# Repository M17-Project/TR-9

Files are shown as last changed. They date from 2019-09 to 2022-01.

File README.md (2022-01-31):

# TR-9

TR-9 is a handheld transceiver (HT) for the M17 standard. Its specification can be found [here](https://github.com/sp5wwp/M17_spec).
This repo contains KiCAD schematics and gerber files. 

The source code has been moved to [M17-project/TR-9_firmware](https://github.com/m17-project/TR-9_firmware).
The codeplug example has been moved to [TR-9_Codeplug](https://github.com/M17-Project/codeplug)

# Capabilities
The TR-9 Radio will be capable of the following:
* UHF band (420 MHz - 450 MHz)
* Digital Voice ([M17 Codec](https://docs.m17project.org))
* FM Voice
* APRS via 1200 bps Packet (AX.25)
* Short text messaging (SMS-like)
* Optional Wi-Fi and GPS modules

# Hardware  
The heart of TR-9 is STM32F777VI microcontroller. The handheld also contains:  
*  a **DEM 128128A1 TMH-PWN** 1.44" 128x128px TFT display  
*  an **ESP8266-12F** WiFi module  
*  an **ADF7021** chip for the RF  
*  an **LSM9DS1** 9DoF sensor  
*  a USB-micro connector for firmware update (so-called *DFU mode*)  
*  an SD-micro card slot for codeplug and storage  
*  a connector for a GNSS module  
*  a Kenwood connector for external MIC/SPK  

RF output level can be regulated by the software. The maximum power output is 3 watts. The radio can work with both analog and digital modulation.  

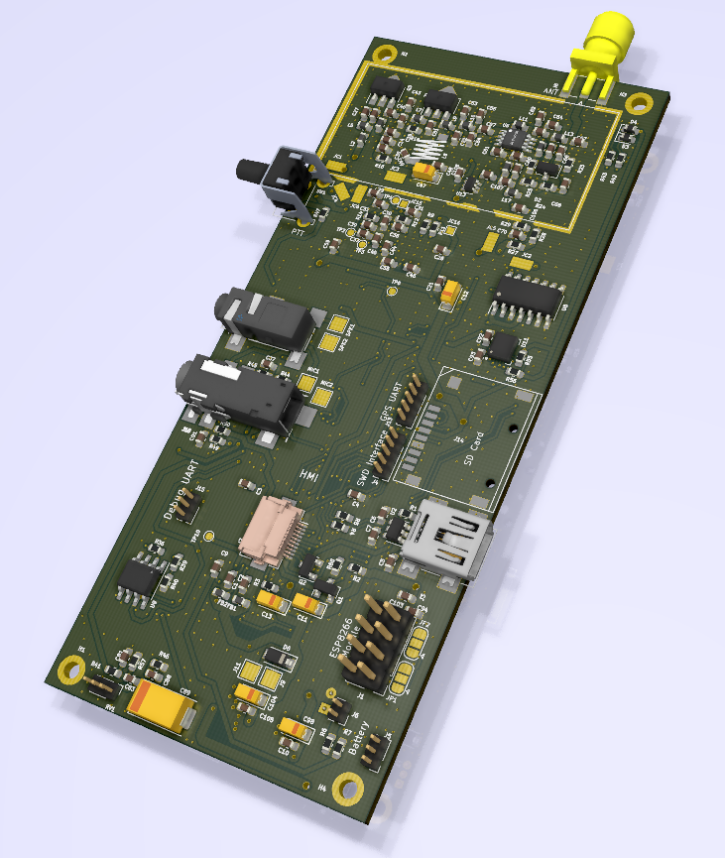
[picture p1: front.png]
TR-9


# Software
M17 standard was designed having [Codec2](https://github.com/drowe67/codec2) vocoder in mind. TR-9 takes advantage of STM's internal Advanced Encryption Standard (AES) hardware for optional end-to-end encryption. There is a possibility of using other block ciphers and scrambling.  

## Pinouts

Mainboard SWD/STLink: [GND, 3v3, CLK, DIO, RST], square pad is Pin 1 and therefore GND.

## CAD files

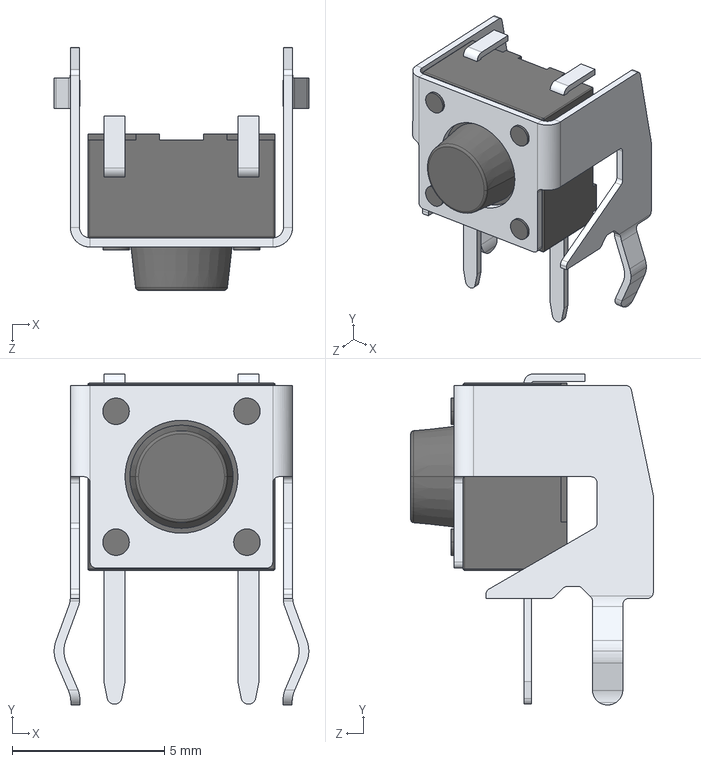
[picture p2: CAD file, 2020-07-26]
kicad/HMI/User Library-Alps TACT SKHH Horizontal Switch.step
8.37 x 10.9 x 7.97 mm

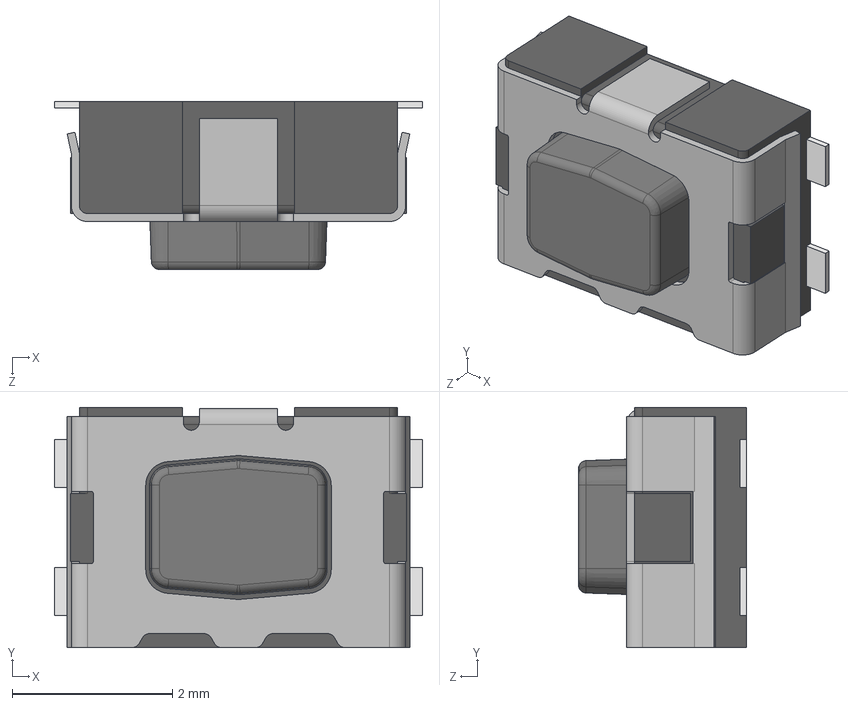
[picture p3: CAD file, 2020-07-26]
kicad/HMI/User Library-Switch-CK-KMR2.STEP
4.60 x 3.00 x 2.10 mm
Button
Boitier
Tole
Pads

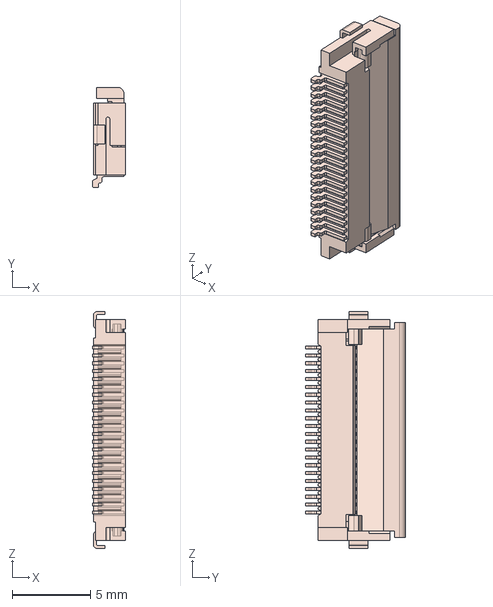
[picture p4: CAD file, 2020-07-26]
kicad/HMI/FH12-22S-0.5SH.step
2.10 x 6.40 x 15.1 mm

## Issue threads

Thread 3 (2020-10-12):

Power output

sp5wwp, 2020-10-12:
1. Power output is limited to 0.6W. Above that, the RF MOSFET gets HOT.
2. There's a high pitched sound audible when PA is active.

ALC circuitry works.

sp5wwp, 2020-10-12:
Squeak was eliminated by adding a 10k resistor in parallel to C106.

sp5wwp, 2020-11-12:
_Maybe_ we should get rid of Q3 (BGA6589).

tkuester, 2020-11-12:
Is this related to issue #8/9 in the errata, about R64 and C106?

sp5wwp, 2020-11-12:
@tkuester yes, it is.

sp5wwp, 2020-11-14:
The RF lowpass stage (around L9, L10) has to be redesigned.

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

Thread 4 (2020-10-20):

AX5043 as RFIC?

radonyl, 2020-10-20:
since APRS(AFSK mod) and analog FM are listed in feature list, I'd recommend AX5043 as the RFIC which has **AFSK demod embedded** (vital for power saving by WOR mode) and also analog mode(even AM). check [this project](https://www.notblackmagic.com/projects/vuhf-radio/) for a proof of practise.

Btw, AX5043's sensitivity is higher -126 vs -122 with even lower price 1.2$ vs 2.4$ and half current 10ma vs 20ma.

sp5wwp, 2020-11-12:
What is the roll-off factor for the Raised Cosine filter (AMPLSHAPE=1)?
I can't find any info here:
https://www.onsemi.com/pub/Collateral/AND9347-D.PDF

sp5wwp, 2022-01-31:
AX5043 is a cool little chip. I'm testing its performance right now. M17 mode TX is possible.

sp5wwp, 2022-01-31:
See [this gist](https://gist.github.com/sp5wwp/c612fc8fe612e99c11f9b65cd50bca3c).

ng91, 2022-01-31:
It's nice chip because it has many modulations that other chips lack of.

f4grx, 2022-02-01:
Definitely!

@sp5wwp thats great! BTW I suggest avoiding floating point in embedded code :)

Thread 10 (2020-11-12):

LED control lines

sp5wwp, 2020-11-12:
We need to add LED control lines (uhm... cathodes) to the interconnecting ribbon.

tkuester, 2020-11-12:
Would we like a power/status LEDs as well? What would we like them to represent? Which board do they belong on, the HMI or the Mainboard?

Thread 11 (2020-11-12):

Battery connector

sp5wwp, 2020-11-12:
Pads are too small, it's hard to solder wires to them.

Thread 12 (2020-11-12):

Unify edge mount tactile switch parts

tkuester, 2020-11-12:
Currently, both boards use the SKHH right angle through hole tactile switch, but they use different button depths. For ease of enclosure design and to reduce unique parts on the PCB, this should be consolidated.

What depth should we use for the next revision?

This issue from `ERRATA.txt`

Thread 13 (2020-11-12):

Split this repo

sp5wwp, 2020-11-12:
Split this repo into 3:
- firmware
- case design
- schematics/gerbers/BOM

tkuester, 2020-11-12:
I think this is a good decision -- especially for the firmware, which will change much faster than the hardware. At least for maintaining tags, there may be several revisions of firmware.

There may be some small utility in tracking the case design and PCB files all within one repository, such as keeping all the hardware issues in one place. If we wish to do things more incrementally (than all at once), perhaps it would be best to start with just two repositories: the firmware and hardware? This may be a little easier for other members in the project to track.

Closed 2020-11-14.

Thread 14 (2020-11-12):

HMI: Select the correct strap options for boot mode on the STM32

tkuester, 2020-11-12:
Per `ERRATA.txt`, pins 31 and 32 on U1 (STM32L011) should be shorted together to select the correct boot state. Tentatively, I've labeled this "bug", although I'm not sure what the implications of it are yet.

I suspect the best way to do this is with a pull down resistor. That is a little less "permanent" of a change, and permits easier bodge-wiring at a later date. Perhaps we can reuse a 47k 0603 -- or alternatively, kicad's "Jumper" if we want to save on soldering another part.

I took a brief look at the [datasheet, section 3.4.4](https://www.st.com/resource/en/datasheet/stm32l011d4.pdf). It indicates that there are several pins which control boot mode, can anyone confirm this needs to take place?

sp5wwp, 2020-11-12:
We probably wont have to leave that pin floating, so a pulldown or even a hard-tie to GND is OK.

tkuester, 2020-11-14:
Doing a bit more reading on the STM32 boot modes. I now understand that `PB9` is `BOOT0`, and `nBOOT{0,1}` and `nBOOT_SEL` are configuration bits.

I had to push some traces around a little to get the resistor to fit, but I don't think this is worth pushing yet -- I still don't understand enough about the STM32 to consider this ready. Is there any reason we would want `BOOT0` to be logic high? Or would this be a recovery scenario, and a bodge wire is tolerable?

I'm going to make a separate issue with a documentation request for compiling and flashing the firmware -- I think this would help better understand what the board needs!

sp5wwp, 2020-11-14:
There's no reason to put logic high on that pin.

Since it can be fixed with a solder blob, I'd leave this as is, mention this in ERRATA.txt and move on.

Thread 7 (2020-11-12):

Unify SWD header on TR-9 with HMI

tkuester, 2020-11-12:
As of 9ac1f05, the HMI board and the TR-9 share a different header layout for the SWD interface. Per a conversation with @sp5wwp, it would be nice to unify the headers to a common standard.

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

Some considerations I think are important:

 * Having the same ordering, and number of pins. If pin 1 (square pad) is GND on one board, it should be the same on the other
 * Having a common interface with common STM32 programmers. (Regrettably, I am new to the STM32 ecosystem, I'm not sure what's common.) SP5WWP indicated that the 1.27mm pin headers are frustrating to work with
 * A silk screen indicating to the user which pin does what
 * Consideration for accessibility. It would be nice to be able to access the headers without having to entirely disassemble the module!

sp5wwp, 2020-11-14:
- Pin 1 can be GND on both connectors. Both should have the same ordering.
- SWD uses SWCLK, SWDIO, /RST (and GND) signals. I'm not sure if there's any "common connector".
- Info on the silk screen is OK if one can manage to put it there :-)
- We can use anything as the connector. It's worth noticing that HMI board won't receive frequent firmware updates.

tkuester, 2020-11-15:
I have a proposal for the SWD connector.

Programmers like [this](https://www.amazon.com/HiLetgo-Emulator-Downloader-Programmer-STM32F103C8T6/dp/B07SQV6VLZ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) are relatively cheap and easy to come by. (~$6 USD) Do you think we could use the header for this?

Alternatively, I have an STM32 Nucleo-64 development board on my desk, and the pin order is:

1 - VDD_TARGET
2 - SWCLK
3 - GND
4 - SWDIO
5 - nRST

I'm still new to the STM32 platform, I'm just looking for "standards" that are pre-existing.

sp5wwp, 2020-11-15:
We can use that mapping. Also: it is not necessary to use VDD_TARGET line.

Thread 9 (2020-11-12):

Switch to a thruhole SMA connector on the Mainboard

tkuester, 2020-11-12:
Currently, the board uses an edge launch SMA connector. @sp5wwp believes it would be sturdier as a right angle thru hole component. Please list recommended parts and footprints here!

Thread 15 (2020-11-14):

Documentation Request

tkuester, 2020-11-14:
Currently, there isn't much information on the board or firmware. Though we are discussing splitting the repository (#13), I think it would be beneficial to begin some rudimentary documentation on bringing the board up online, compiling the firmware, and flashing the unit. "Getting started", if you will!

It would be nice if we had some pictures of assembled and functioning units, as well. Does anyone have a picture? Preliminarily, I'm assigning this to SP5WWP, as I've had the most communication with him about the board.

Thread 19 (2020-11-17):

Voltage regulators

sp5wwp, 2020-11-17:
Both linear regs get warm, how about using DC/DC converters? I know it's an RFI issue ;-)

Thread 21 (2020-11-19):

Move the SWD connector on the HMI board

sp5wwp, 2020-11-19:
Move the connector closer to the edge of the PCB, so that it's not hidden below the display.

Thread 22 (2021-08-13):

USB-C, discussion

uranuspucksaxophone, 2021-08-13:
Should we add USB Type C as a connector?

Pros:

- USB A, B is deprecated
- USB-C is more durable

engammar, 2021-09-03:
USB c would general standard

f4grx, 2021-09-06:
USB micro-B female to USB-C male adapters are easy to find. I recommend USB-C as more modern, durable, reversible, and also, allowing more current to the battery and/or PA.

Also, USB-C allows host more more easily (for usb key, etc).

sp5wwp, 2022-01-16:
We can change it in the next revision, but I have no idea when that's going to happen :-)

tkuester, 2022-01-17:
As a note, for future me!

When using USB-C, don't forget the CC resistors! That burned me on a recent design.

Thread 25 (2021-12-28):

GNSS Integration

KE7KUS, 2021-12-28:
Considerations for adding on-board GNSS via a small GNSS SiP chip like the u-blox ZOE-M8B:

[u-blox ZOE-M8B Datasheet](https://www.u-blox.com/sites/default/files/ZOE-M8B_DataSheet_UBX-17035164.pdf)

Pro's:
1)  Provides SPS accuracy (~3.5m) at extremely low power consumption (<7mA in energy-saving mode).
2)  Small form factor (4mmx4mm) could potentially replace the GPS UART header with some clever board re-work - built-in UART interface in chip means relatively easy integration into existing GPS data traces.
3)  When used with companion RTC chip, provides accurate long-term date/time retention for firmware use.
4)  Adds GNSS logging function when used with external storage (SD card).
5)  Provides odometer function which can be accessed by a firmware modification to allow "distance traveled" tracking.
6)  Some signal processing hardening against GNSS interference/spoofing.
7)  Multi-system compatibility (US GPS, GLONASS, Galileo, etc.) for international applicability.
8)  Autonomous GNSS ephemeris downlink/storage (3 days w/ onboard ROM or 6 days w/ external storage (SD card) - enables fast starts from power-off or standby state.
9)  Compatible with some position enhancing services (SBAS, D-GPS, etc.)

Con's:
1)  Cost ($29 USD/per when purchased in 1 qty or $14 USD/per when purchased in 1000+ qty from DigiKey as of 12/28/21).
2)  Requires GNSS antenna integration solution either on the mainboard (performance & space limitations) or into mainboard case (requires external case engineering + GPS antenna port added to main board).
3)  ZOE-M8B has no PPS output for precise timing applications (frequency agile/hopping waveforms).  Other chips may be substituted which provide PPS output, but potentially at a larger real-estate cost on the board.

Thoughts?

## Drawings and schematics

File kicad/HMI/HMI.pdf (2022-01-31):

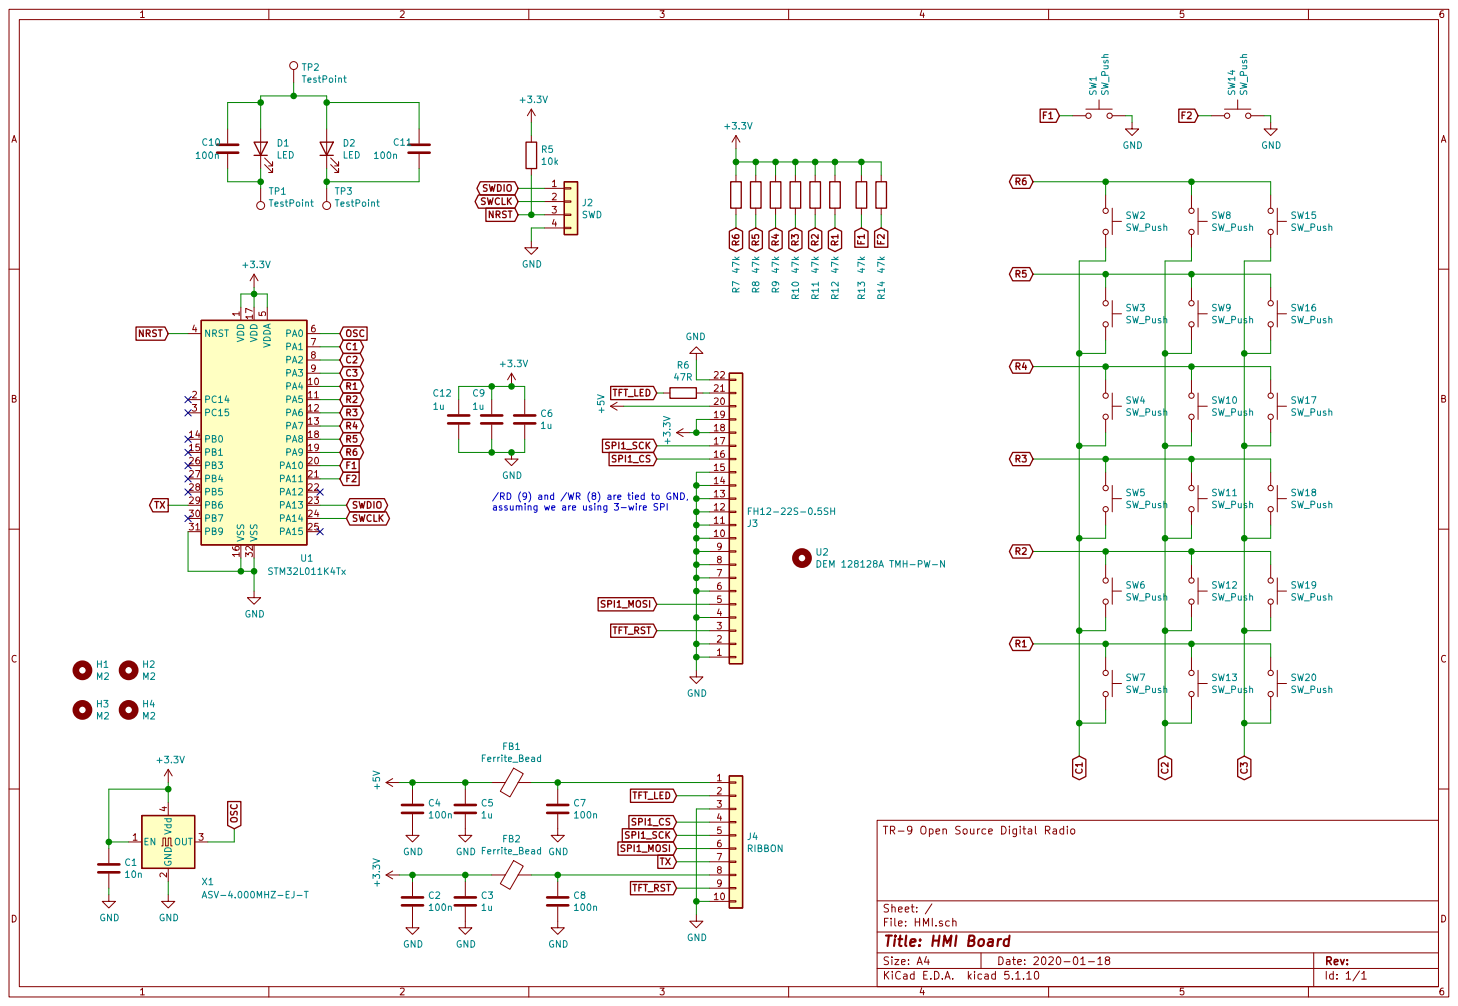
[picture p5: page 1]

/RD (9) and /WR (8) are tied to GND,
assuming we are using 3-wire SPI

File: HMI.sch Sheet: / TR-9 Open Source Digital Radio

Id: 1/1 Title: HMI Board

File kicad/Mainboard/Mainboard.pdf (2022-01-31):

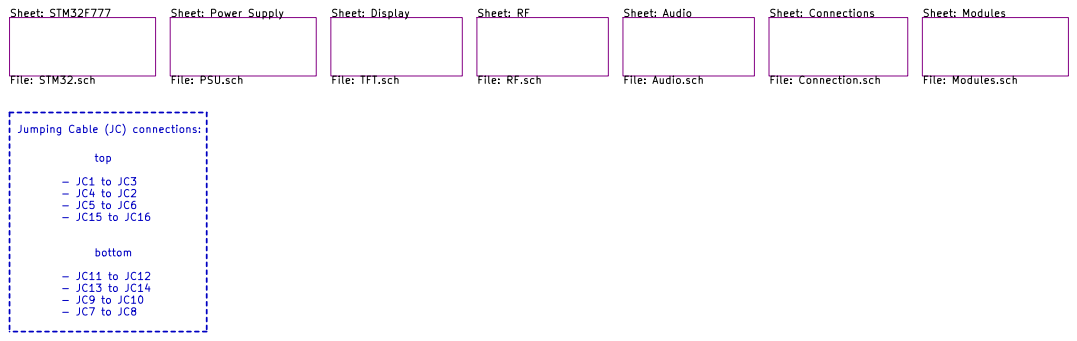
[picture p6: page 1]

Jumping Cable (JC) connections:

TR-9 Open Source Digital Radio
File: Mainboard.sch Sheet: / Author: DB9MAT Mathis, SO3ALG Nikoloz, SP5WWP Wojciech

Id: 1/8 Title: TR-9 Mainboard

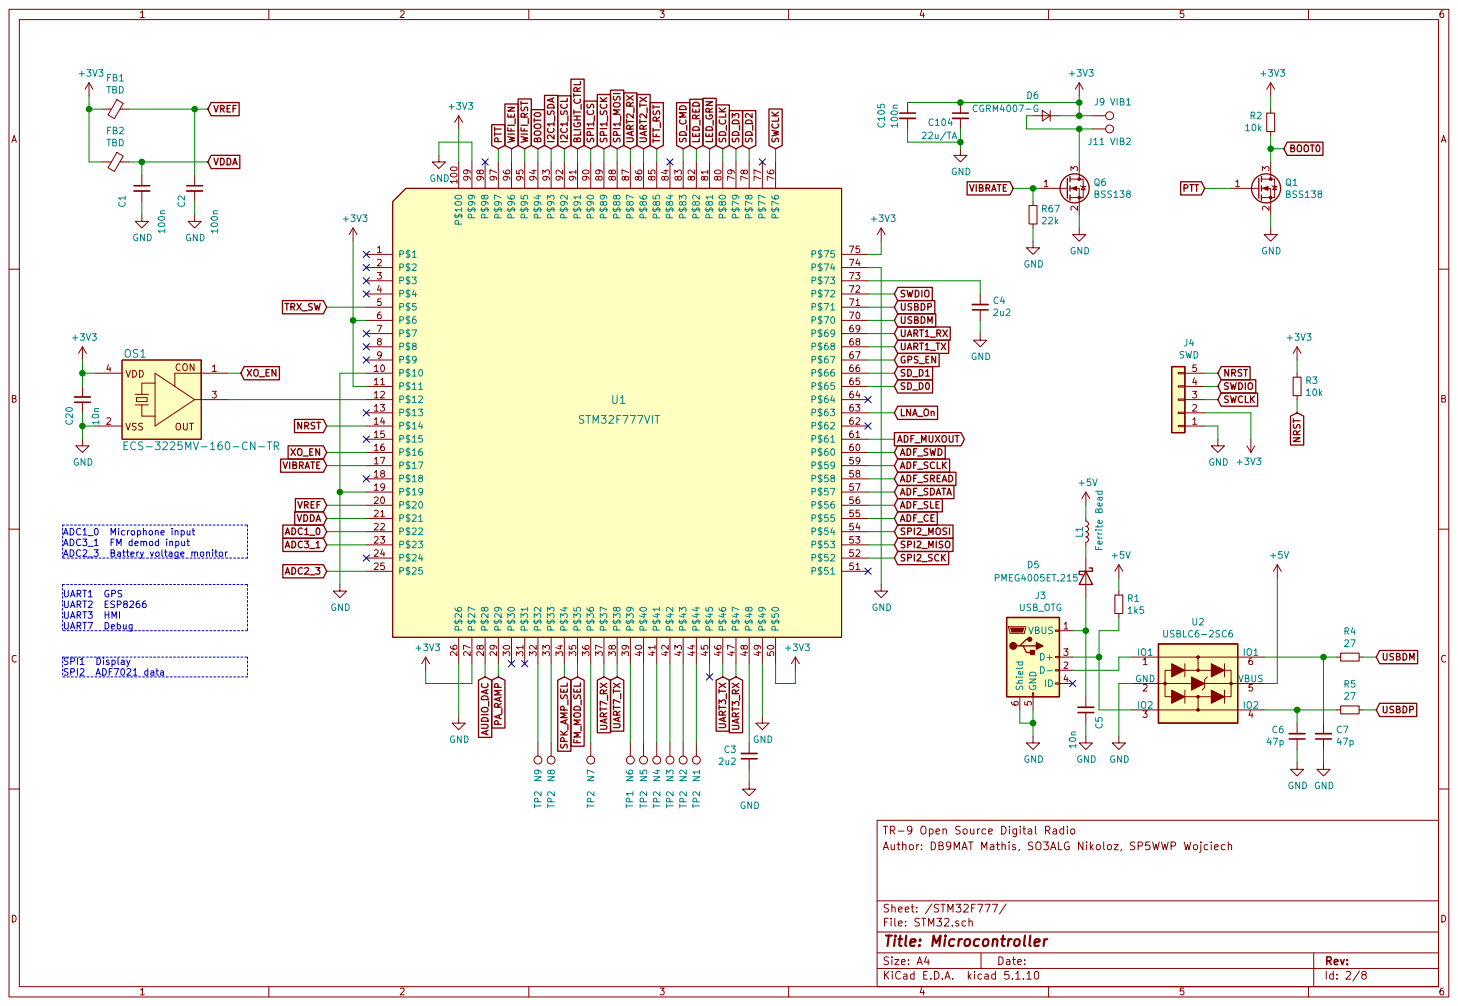
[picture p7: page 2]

J9 VIB1 GND CON OUT VDD

ADC1_0 Microphone input
ADC3_1 FM demod input
ADC2_3 Battery voltage monitor UART1 GPS UART2 ESP8266 UART3 HMI UART7 Debug

Id: 2/8 Title: Microcontroller File: STM32.sch Sheet: /STM32F777/ Author: DB9MAT Mathis, SO3ALG Nikoloz, SP5WWP Wojciech

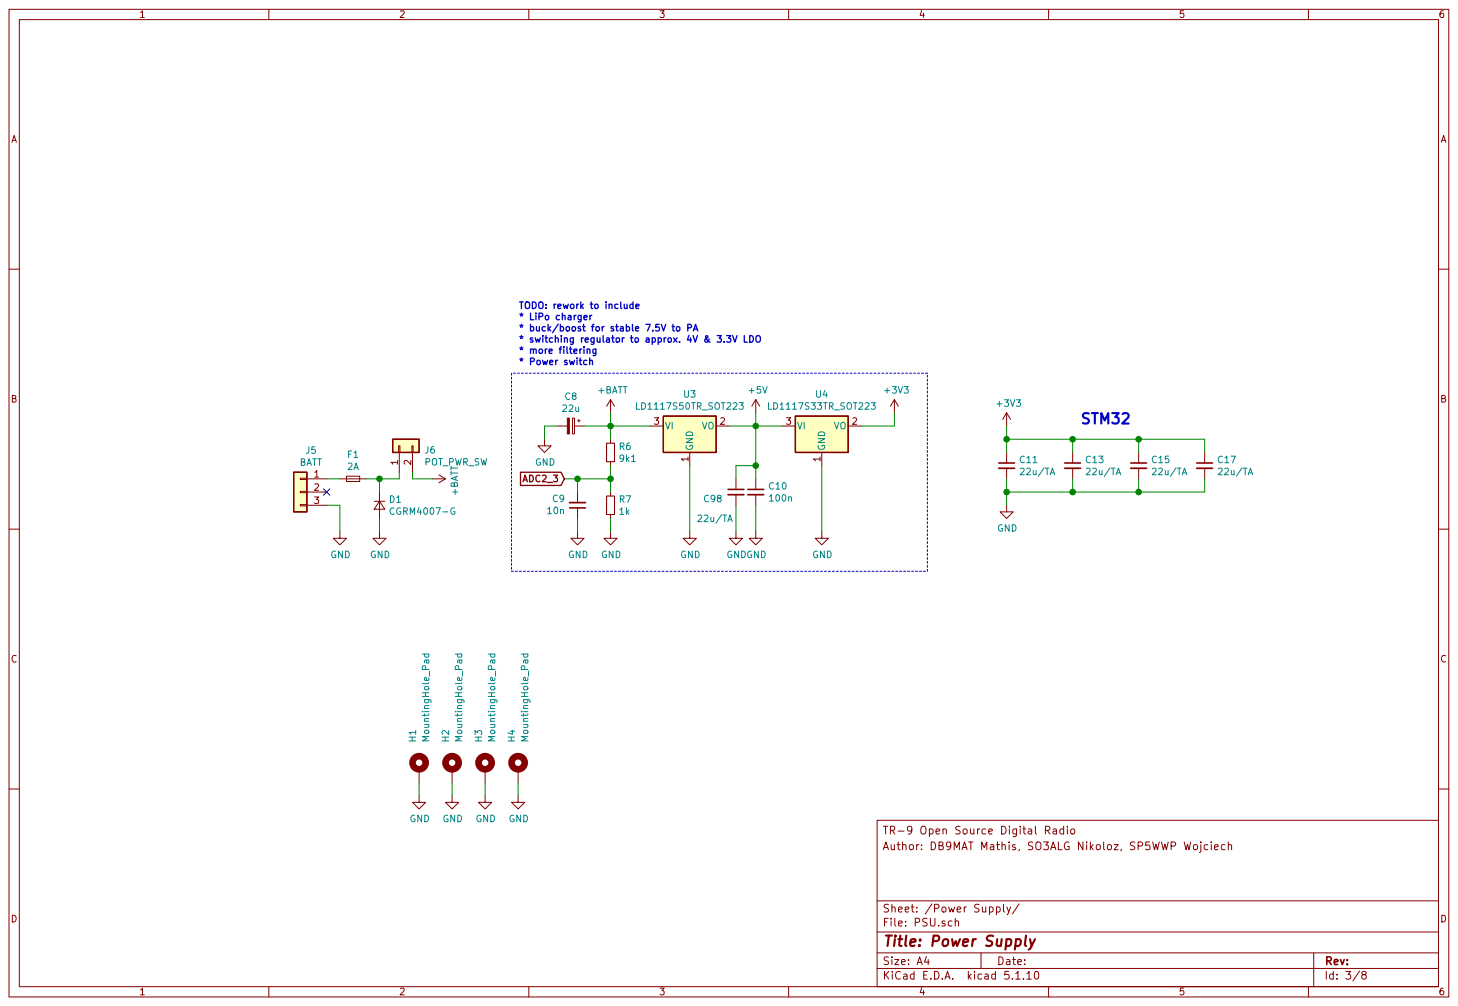
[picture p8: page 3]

9k1 ADC2_3 TODO: rework to include
* LiPo charger
* buck/boost for stable 7.5V to PA
* switching regulator to approx. 4V & 3.3V LDO
* more filtering

TR-9 Open Source Digital Radio
Author: DB9MAT Mathis, SO3ALG Nikoloz, SP5WWP Wojciech

File: PSU.sch Sheet: /Power Supply/
Id: 3/8 Title: Power Supply

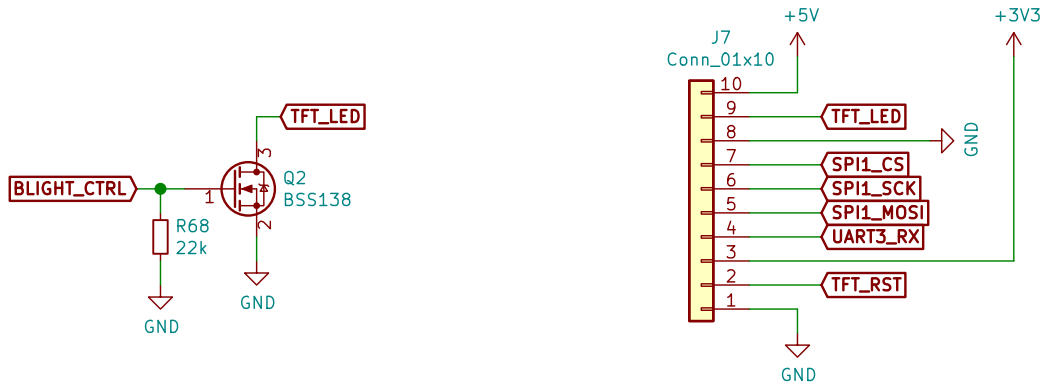
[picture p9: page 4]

TR-9 Open Source Digital Radio GND

Author: DB9MAT Mathis, SO3ALG Nikoloz, SP5WWP Wojciech

Id: 4/8 Title: HMI Board Connector File: TFT.sch Sheet: /Display/

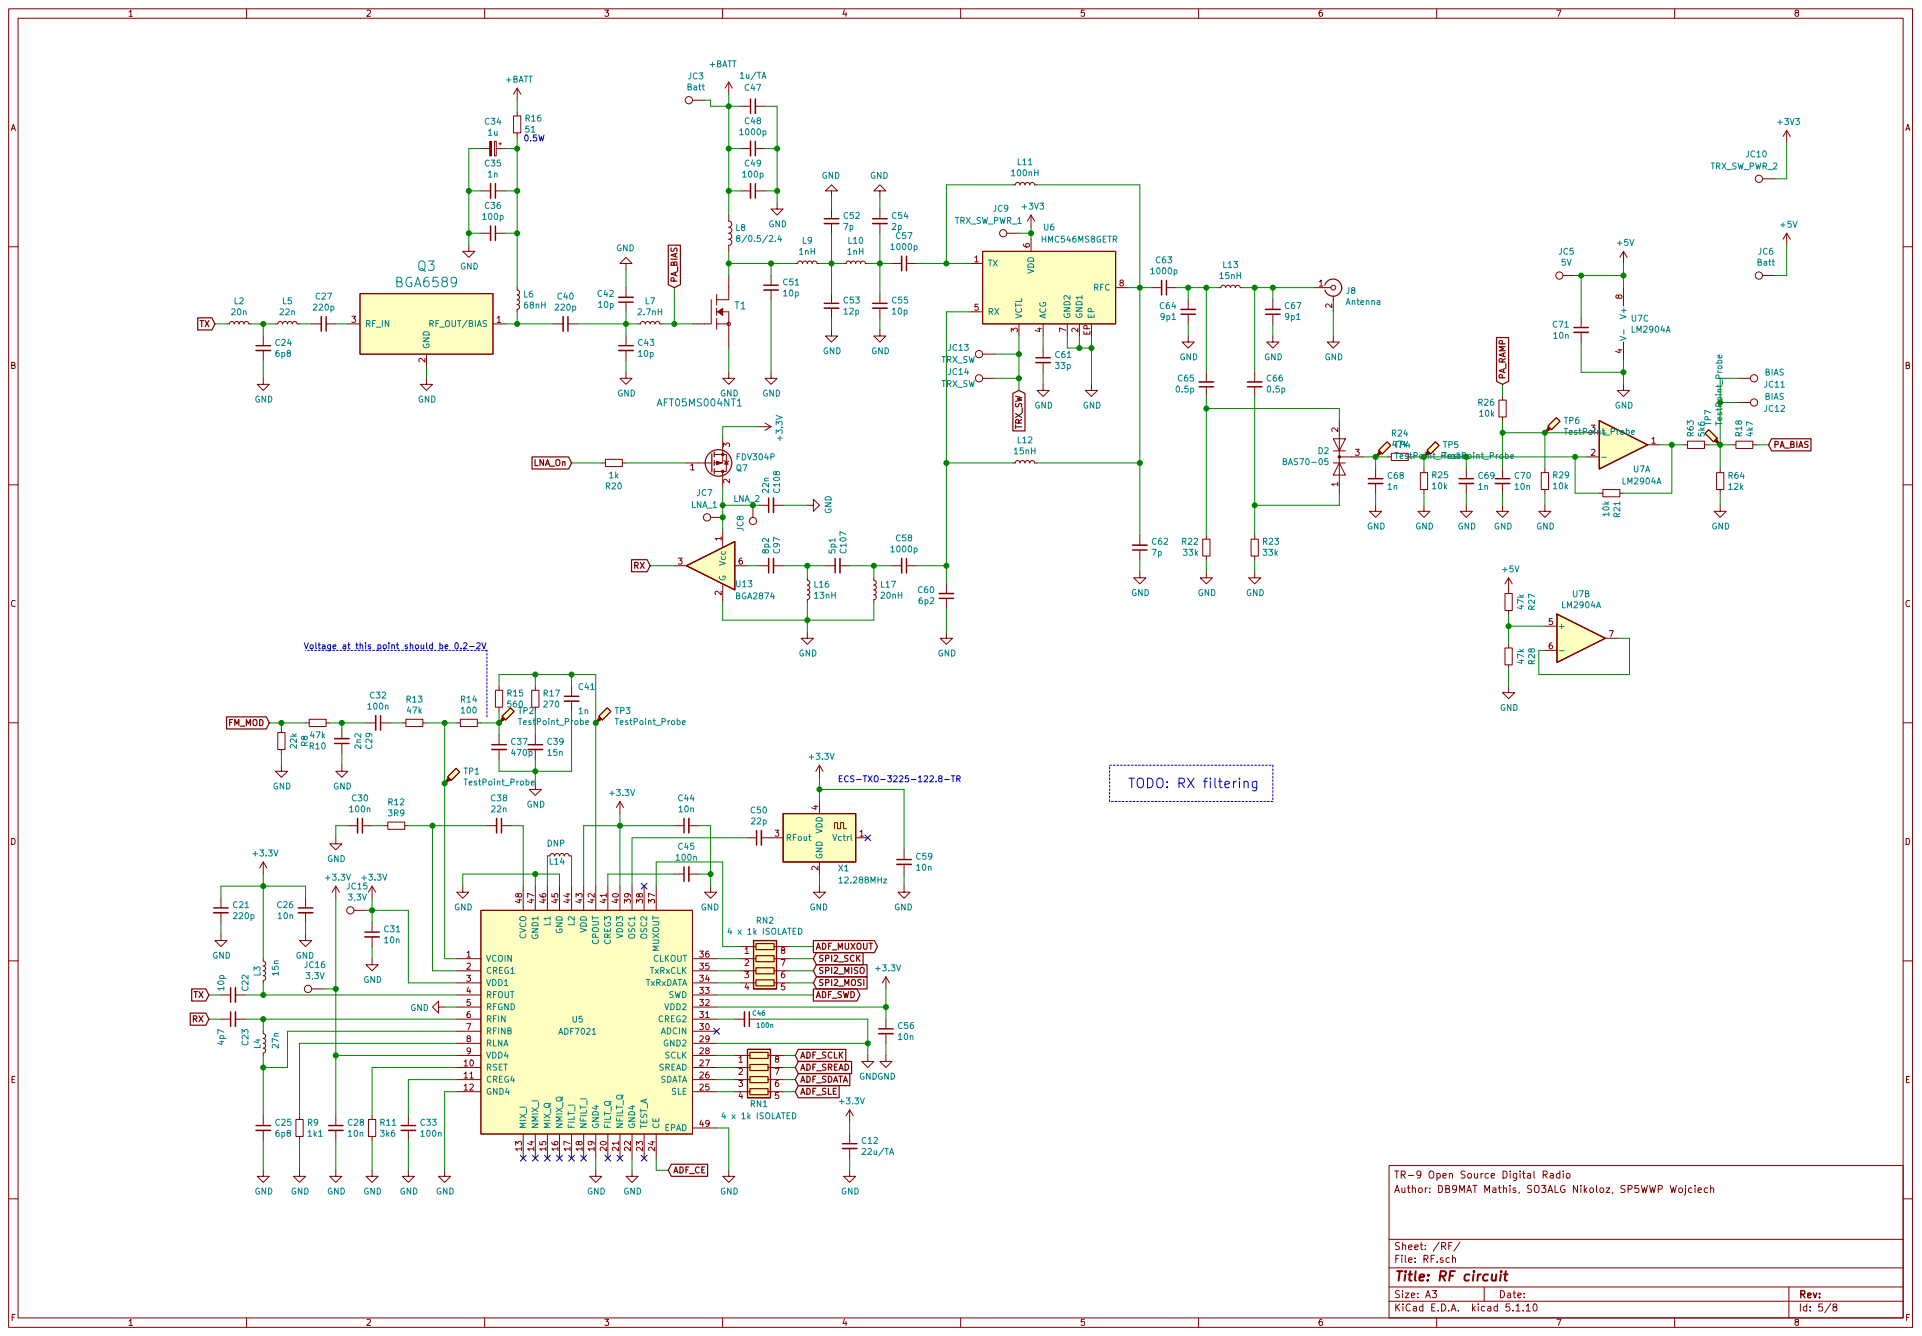
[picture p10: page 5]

Voltage at this point should be 0.2-2V

TR-9 Open Source Digital Radio C26

Id: 5/8 Title: RF circuit File: RF.sch Sheet: /RF/ Author: DB9MAT Mathis, SO3ALG Nikoloz, SP5WWP Wojciech

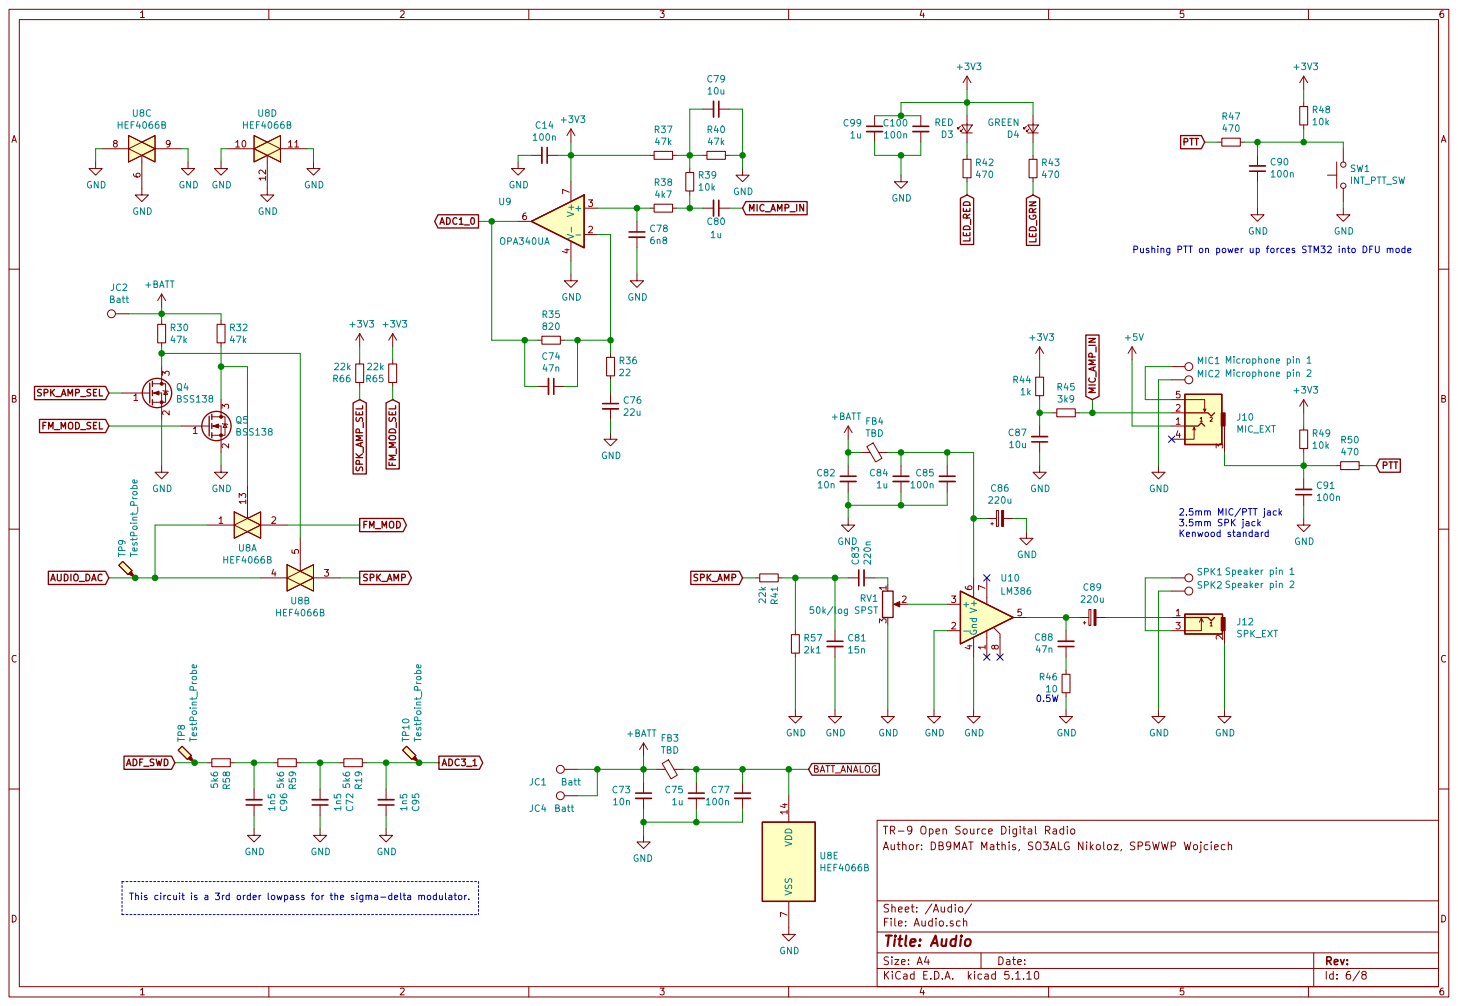
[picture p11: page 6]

Pushing PTT on power up forces STM32 into DFU mode

TR-9 Open Source Digital Radio
File: Audio.sch Sheet: /Audio/ Author: DB9MAT Mathis, SO3ALG Nikoloz, SP5WWP Wojciech

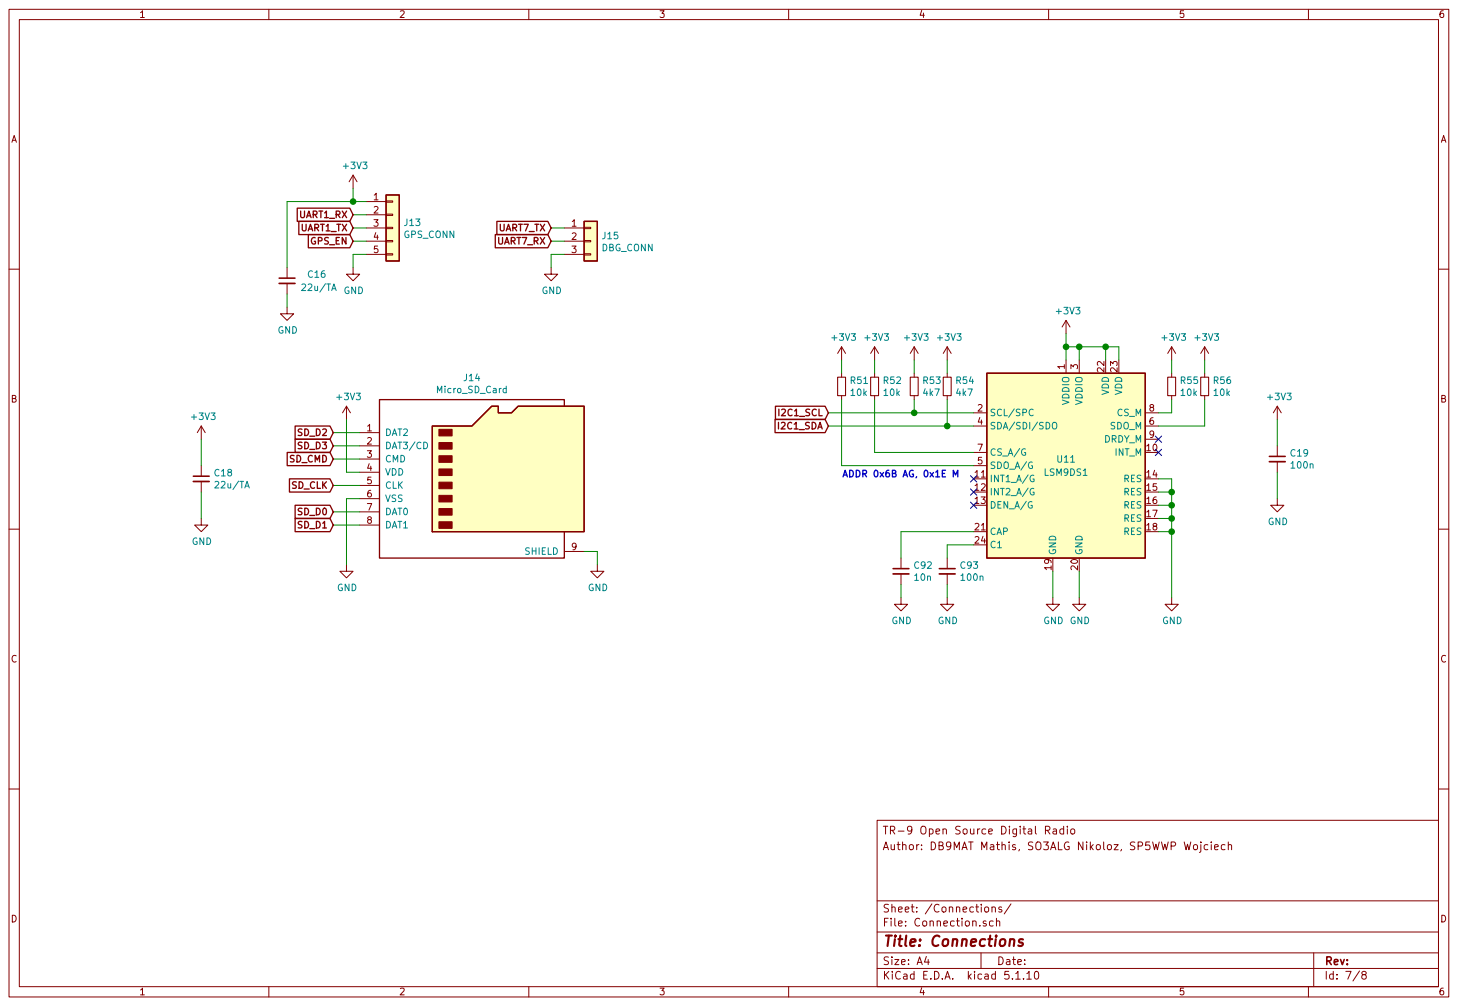
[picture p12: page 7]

TR-9 Open Source Digital Radio
File: Connection.sch Sheet: /Connections/ Author: DB9MAT Mathis, SO3ALG Nikoloz, SP5WWP Wojciech

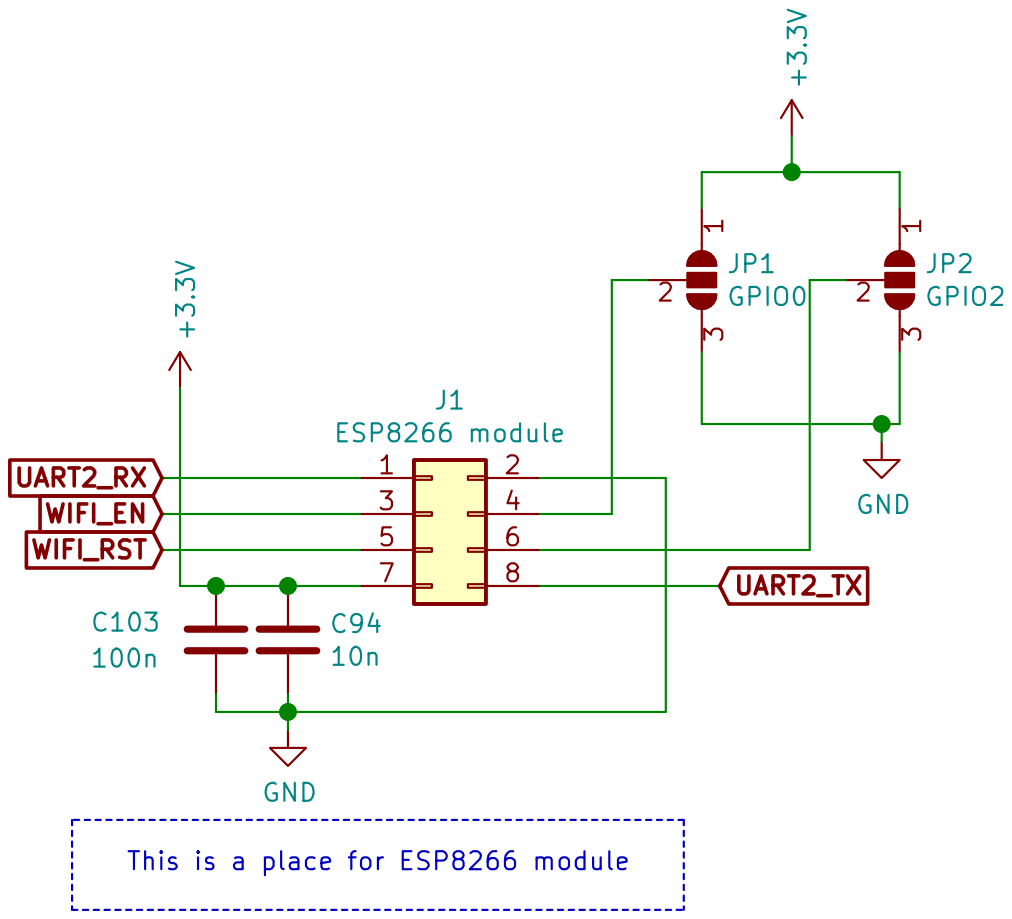
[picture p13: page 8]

TR-9 Open Source Digital Radio C103

This is a place for ESP8266 module

File: Modules.sch Sheet: /Modules/ Author: DB9MAT Mathis, SO3ALG Nikoloz, SP5WWP Wojciech

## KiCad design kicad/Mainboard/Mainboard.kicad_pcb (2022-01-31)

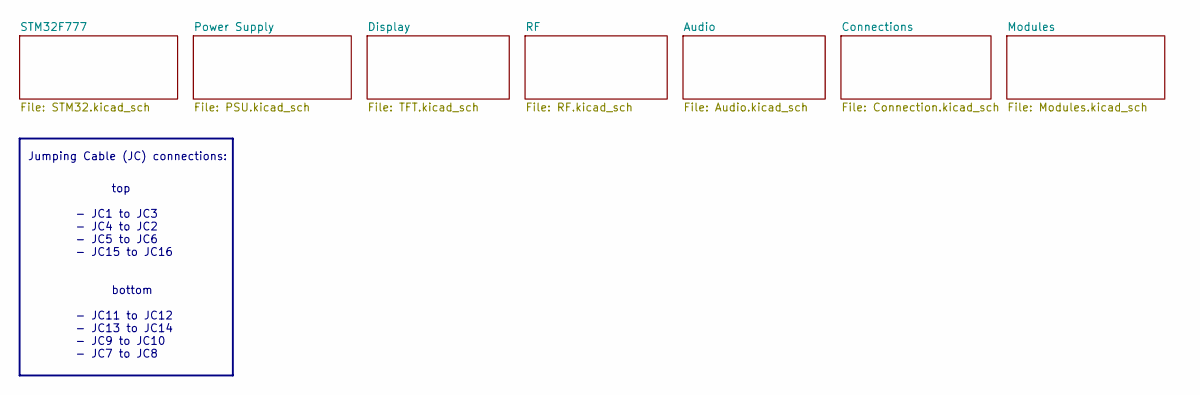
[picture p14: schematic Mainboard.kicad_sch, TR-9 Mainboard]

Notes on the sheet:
top - JC1 to JC3 - JC4 to JC2 - JC5 to JC6 - JC15 to JC16 bottom - JC11 to JC12 - JC13 to JC14 - JC9 to JC10 - JC7 to JC8
Jumping Cable (JC) connections:

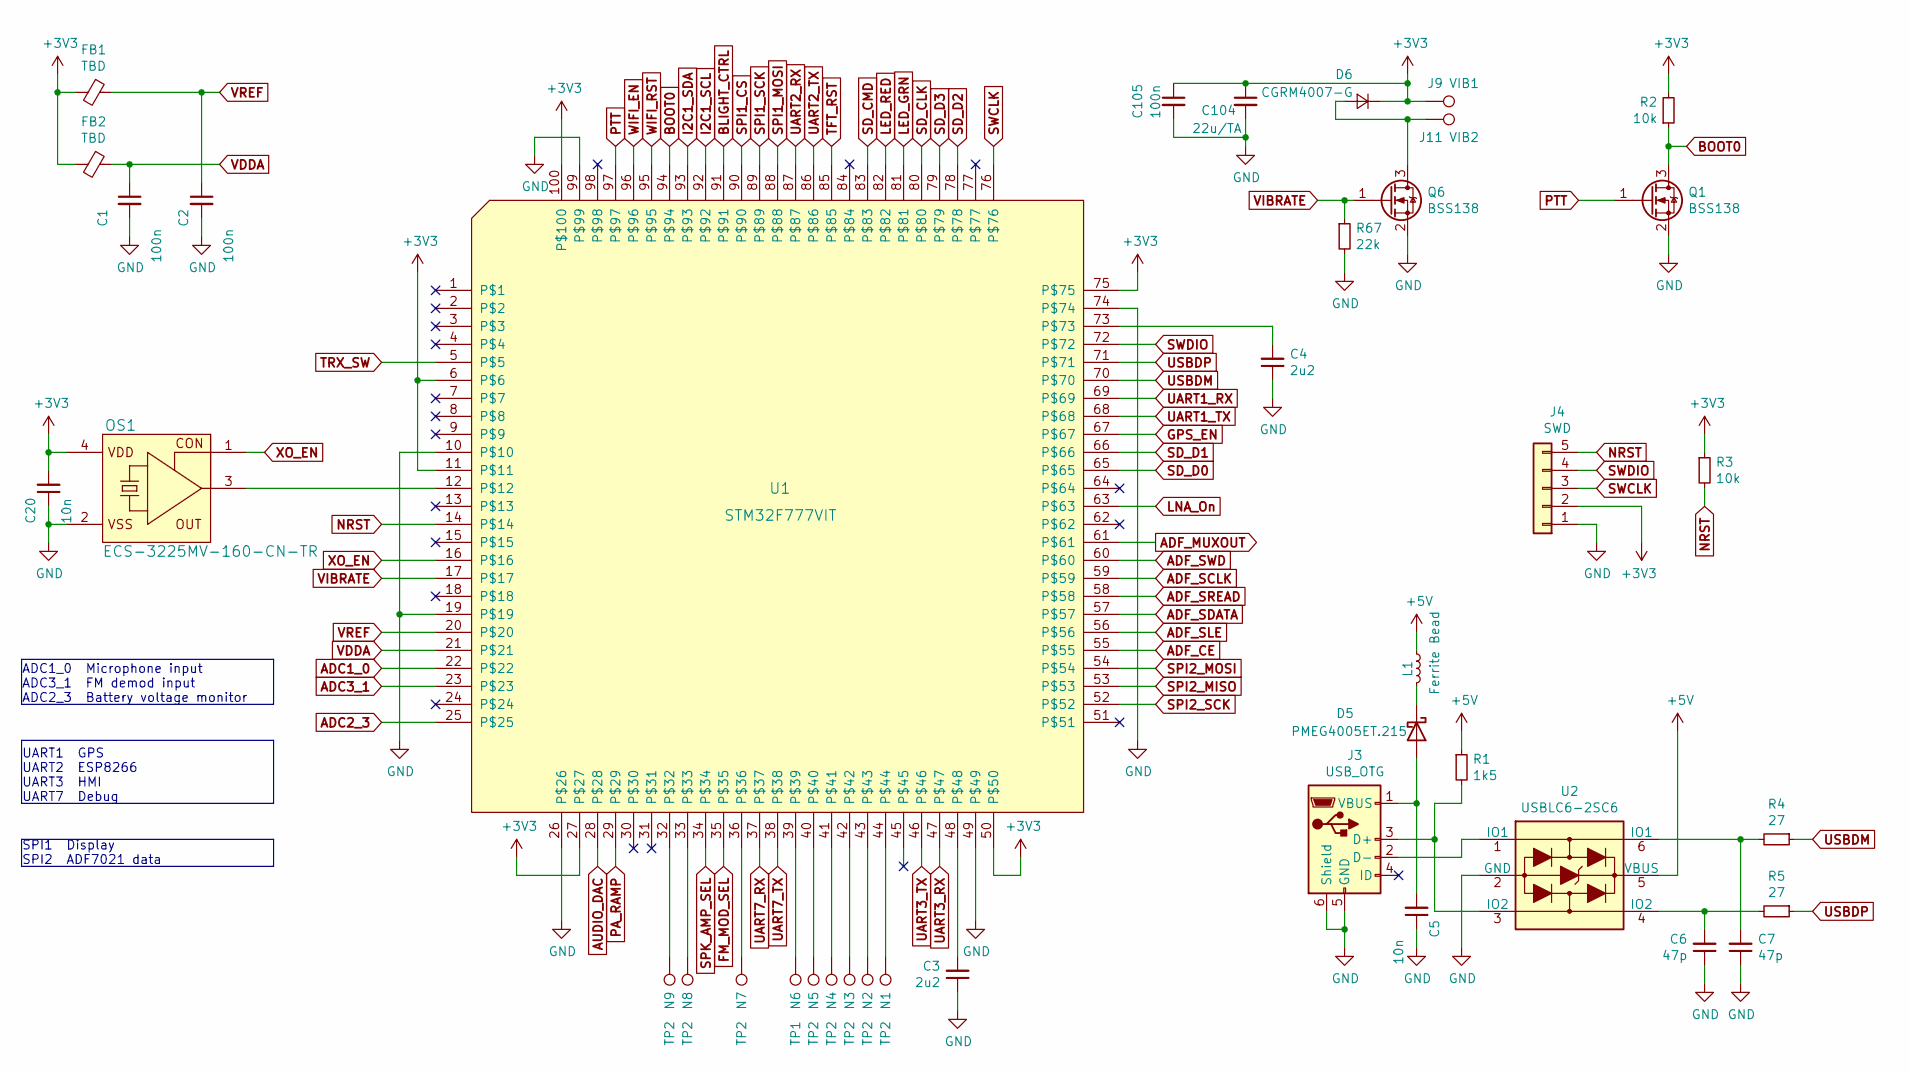
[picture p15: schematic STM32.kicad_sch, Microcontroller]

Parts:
C1, C2, C105: 100n; C_0603_1608Metric; Voltage 50; Tolerance 10
C3, C4: 2u2; C_0603_1608Metric; Tolerance 10; Voltage 50
C5: 10n; C_0603_1608Metric; Voltage 50; Tolerance 10
C6, C7: 47p; C_0603_1608Metric; Tolerance 5; Voltage 50
C20: 10n; C_0603_1608Metric; Tolerance 10; Voltage 50
C104: 22u/TA; CP_EIA-3216-18_Kemet-A; Tolerance 10; Voltage 10; Partno TAJA226K006RNJV
D5: PMEG4005ET.215
D6: CGRM4007-G; D_SOD-123
FB1, FB2: TBD; L_0603_1608Metric
J3: USB_OTG; USB_Mini-B_Wuerth_65100516121_Horizontal
J4: SWD; PinHeader_1x05_P1.27mm_Vertical
J9: VIB1; TestPoint_Pad_2.0x2.0mm
J11: VIB2; TestPoint_Pad_2.0x2.0mm
L1: Ferrite Bead; L_0603_1608Metric; Partno Fair-Rite 2506032217Y2
N1, N2, N3, N4, N5, N7, N8, N9: TP2; TestPoint_Pad_D1.0mm
N6: TP1; TestPoint_Pad_D1.0mm
OS1: ECS-3225MV-160-CN-TR; ECS-3225-MV-160-CN-TR
Q1, Q6: BSS138; SOT-23
R1: 1k5; R_0603_1608Metric; Tolerance 5
R2, R3: 10k; R_0603_1608Metric; Tolerance 5
R4, R5: 27; R_0603_1608Metric; Tolerance 5
R67: 22k; R_0603_1608Metric; Tolerance 5
U1: STM32F777VIT; LQFP-100_14x14mm_P0.5mm
U2: USBLC6-2SC6; SOT-23-6

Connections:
+5V: L1.1, R1.1, U2.5 (VBUS); also elsewhere on the board
ADC1_0: U1.22; also elsewhere on the board
ADC2_3: U1.25; also elsewhere on the board
ADC3_1: U1.23; also elsewhere on the board
ADF_CE: U1.55; also elsewhere on the board
ADF_MUXOUT: U1.61; also elsewhere on the board
ADF_SCLK: U1.59; also elsewhere on the board
ADF_SDATA: U1.57; also elsewhere on the board
ADF_SLE: U1.56; also elsewhere on the board
ADF_SREAD: U1.58; also elsewhere on the board
ADF_SWD: U1.60; also elsewhere on the board
AUDIO_DAC: U1.28; also elsewhere on the board
BLIGHT_CTRL: U1.91; also elsewhere on the board
BOOT0: Q1.3 (D), R2.1, U1.94
FM_MOD_SEL: U1.35; also elsewhere on the board
GPS_EN: U1.67; also elsewhere on the board
I2C1_SCL: U1.92; also elsewhere on the board
I2C1_SDA: U1.93; also elsewhere on the board
LED_GRN: U1.81; also elsewhere on the board
LED_RED: U1.82; also elsewhere on the board
LNA_On: U1.63; also elsewhere on the board
NRST: J4.5, R3.2, U1.14
unnamed: C3.2, U1.48
unnamed: C4.2, U1.73
unnamed: C5.2, D5.2 (A), J3.1 (VBUS)
unnamed: C6.2, R5.2, U2.4 (IO2)
unnamed: C7.2, R4.2, U2.6 (IO1)
unnamed: D5.1 (K), L1.2
unnamed: D6.2 (A), J11.1, Q6.3 (D)
unnamed: J3.2 (D-), U2.1 (IO1)
unnamed: J3.3 (D+), R1.2, U2.3 (IO2)
unnamed: N1.1, U1.44
unnamed: N2.1, U1.43
unnamed: N3.1, U1.42
unnamed: N4.1, U1.41
unnamed: N5.1, U1.40
unnamed: N6.1, U1.39
unnamed: N7.1, U1.36
unnamed: N8.1, U1.33
unnamed: N9.1, U1.32
unnamed: OS1.3 (OUT), U1.12
PA_RAMP: U1.29; also elsewhere on the board
PTT: Q1.1 (G), U1.97; also elsewhere on the board
SD_CLK: U1.80; also elsewhere on the board
SD_CMD: U1.83; also elsewhere on the board
SD_D0: U1.65; also elsewhere on the board
SD_D1: U1.66; also elsewhere on the board
SD_D2: U1.78; also elsewhere on the board
SD_D3: U1.79; also elsewhere on the board
SPI1_CS: U1.90; also elsewhere on the board
SPI1_MOSI: U1.88; also elsewhere on the board
SPI1_SCK: U1.89; also elsewhere on the board
SPI2_MISO: U1.53; also elsewhere on the board
SPI2_MOSI: U1.54; also elsewhere on the board
SPI2_SCK: U1.52; also elsewhere on the board
SPK_AMP_SEL: U1.34; also elsewhere on the board
SWCLK: J4.3, U1.76
SWDIO: J4.4, U1.72
TFT_RST: U1.85; also elsewhere on the board
TRX_SW: U1.5; also elsewhere on the board
UART1_RX: U1.69; also elsewhere on the board
UART1_TX: U1.68; also elsewhere on the board
UART2_RX: U1.87; also elsewhere on the board
UART2_TX: U1.86; also elsewhere on the board
UART3_RX: U1.47; also elsewhere on the board
UART3_TX: U1.46
UART7_RX: U1.37; also elsewhere on the board
UART7_TX: U1.38; also elsewhere on the board
USBDM: R4.1, U1.70
USBDP: R5.1, U1.71
VDDA: C1.1, FB2.1, U1.21
VIBRATE: Q6.1 (G), R67.1, U1.17
VREF: C2.1, FB1.1, U1.20
WIFI_EN: U1.96; also elsewhere on the board
WIFI_RST: U1.95; also elsewhere on the board
XO_EN: OS1.1 (CON), U1.16

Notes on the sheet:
UART1 GPS UART2 ESP8266 UART3 HMI UART7 Debug
ADC1_0 Microphone input ADC3_1 FM demod input ADC2_3 Battery voltage monitor
SPI1 Display SPI2 ADF7021 data

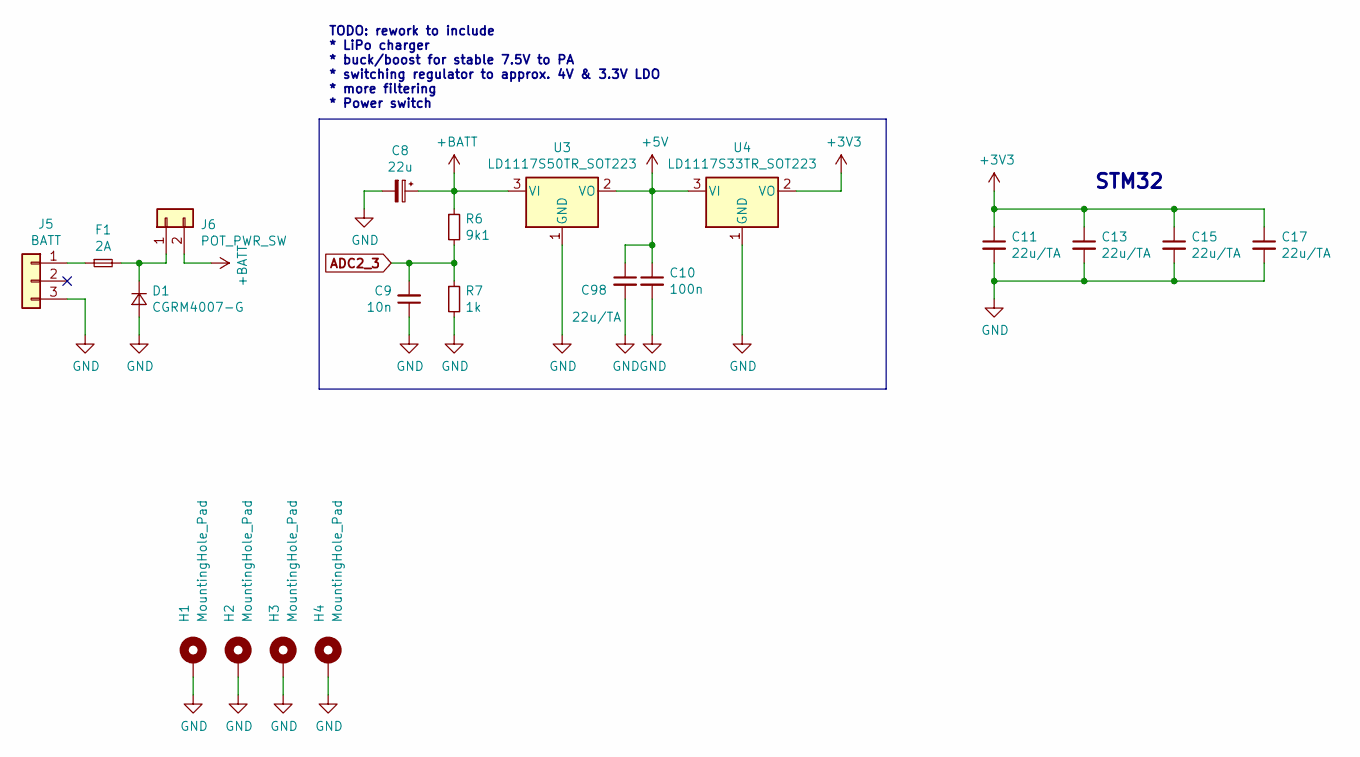
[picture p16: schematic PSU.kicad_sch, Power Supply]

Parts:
C8: 22u; CP_Radial_D4.0mm_P2.00mm; Tolerance 10; Voltage 25; Partno TAJA226K006RNJV
C9: 10n; C_0603_1608Metric; Tolerance 10; Voltage 50
C10: 100n; C_0603_1608Metric; Voltage 50; Tolerance 10
C11, C13, C15, C17, C98: 22u/TA; CP_EIA-3216-18_Kemet-A; Tolerance 10; Voltage 10; Partno TAJA226K006RNJV
D1: CGRM4007-G; D_SOD-123
F1: 2A; Fuse_1812_4532Metric
H1, H2, H3, H4: MountingHole_Pad; MountingHole_2.2mm_M2_ISO14580_Pad
J5: BATT; PinHeader_1x03_P1.27mm_Vertical
J6: POT_PWR_SW; PinHeader_1x02_P1.27mm_Vertical
R6: 9k1; R_0603_1608Metric; Tolerance 5
R7: 1k; R_0603_1608Metric; Tolerance 5
U3: LD1117S50TR_SOT223; SOT-223-3_TabPin2
U4: LD1117S33TR_SOT223; SOT-223-3_TabPin2

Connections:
+5V: C10.1, C98.1, U3.2 (VO), U4.3 (VI); also elsewhere on the board
+BATT: C8.1, J6.2, R6.1, U3.3 (VI); also elsewhere on the board
ADC2_3: C9.2, R6.2, R7.1; also elsewhere on the board
unnamed: D1.1 (K), F1.2, J6.1
unnamed: F1.1, J5.1

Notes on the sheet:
STM32
TODO: rework to include * LiPo charger * buck/boost for stable 7.5V to PA * switching regulator to approx. 4V & 3.3V LDO * more filtering * Power switch

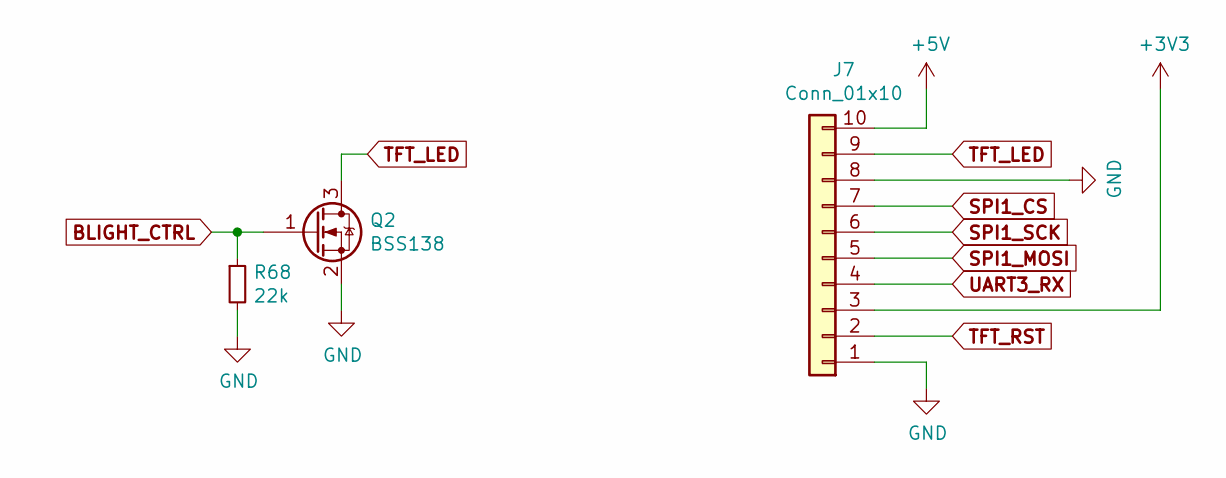
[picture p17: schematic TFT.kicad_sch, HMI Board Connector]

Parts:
J7: Conn_01x10; Hirose_FH12-10S-0.5SH_1x10-1MP_P0.50mm_Horizontal
Q2: BSS138; SOT-23
R68: 22k; R_0603_1608Metric; Tolerance 5

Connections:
+5V: J7.10; also elsewhere on the board
BLIGHT_CTRL: Q2.1 (G), R68.1; also elsewhere on the board
SPI1_CS: J7.7; also elsewhere on the board
SPI1_MOSI: J7.5; also elsewhere on the board
SPI1_SCK: J7.6; also elsewhere on the board
TFT_LED: J7.9, Q2.3 (D)
TFT_RST: J7.2; also elsewhere on the board
UART3_RX: J7.4; also elsewhere on the board

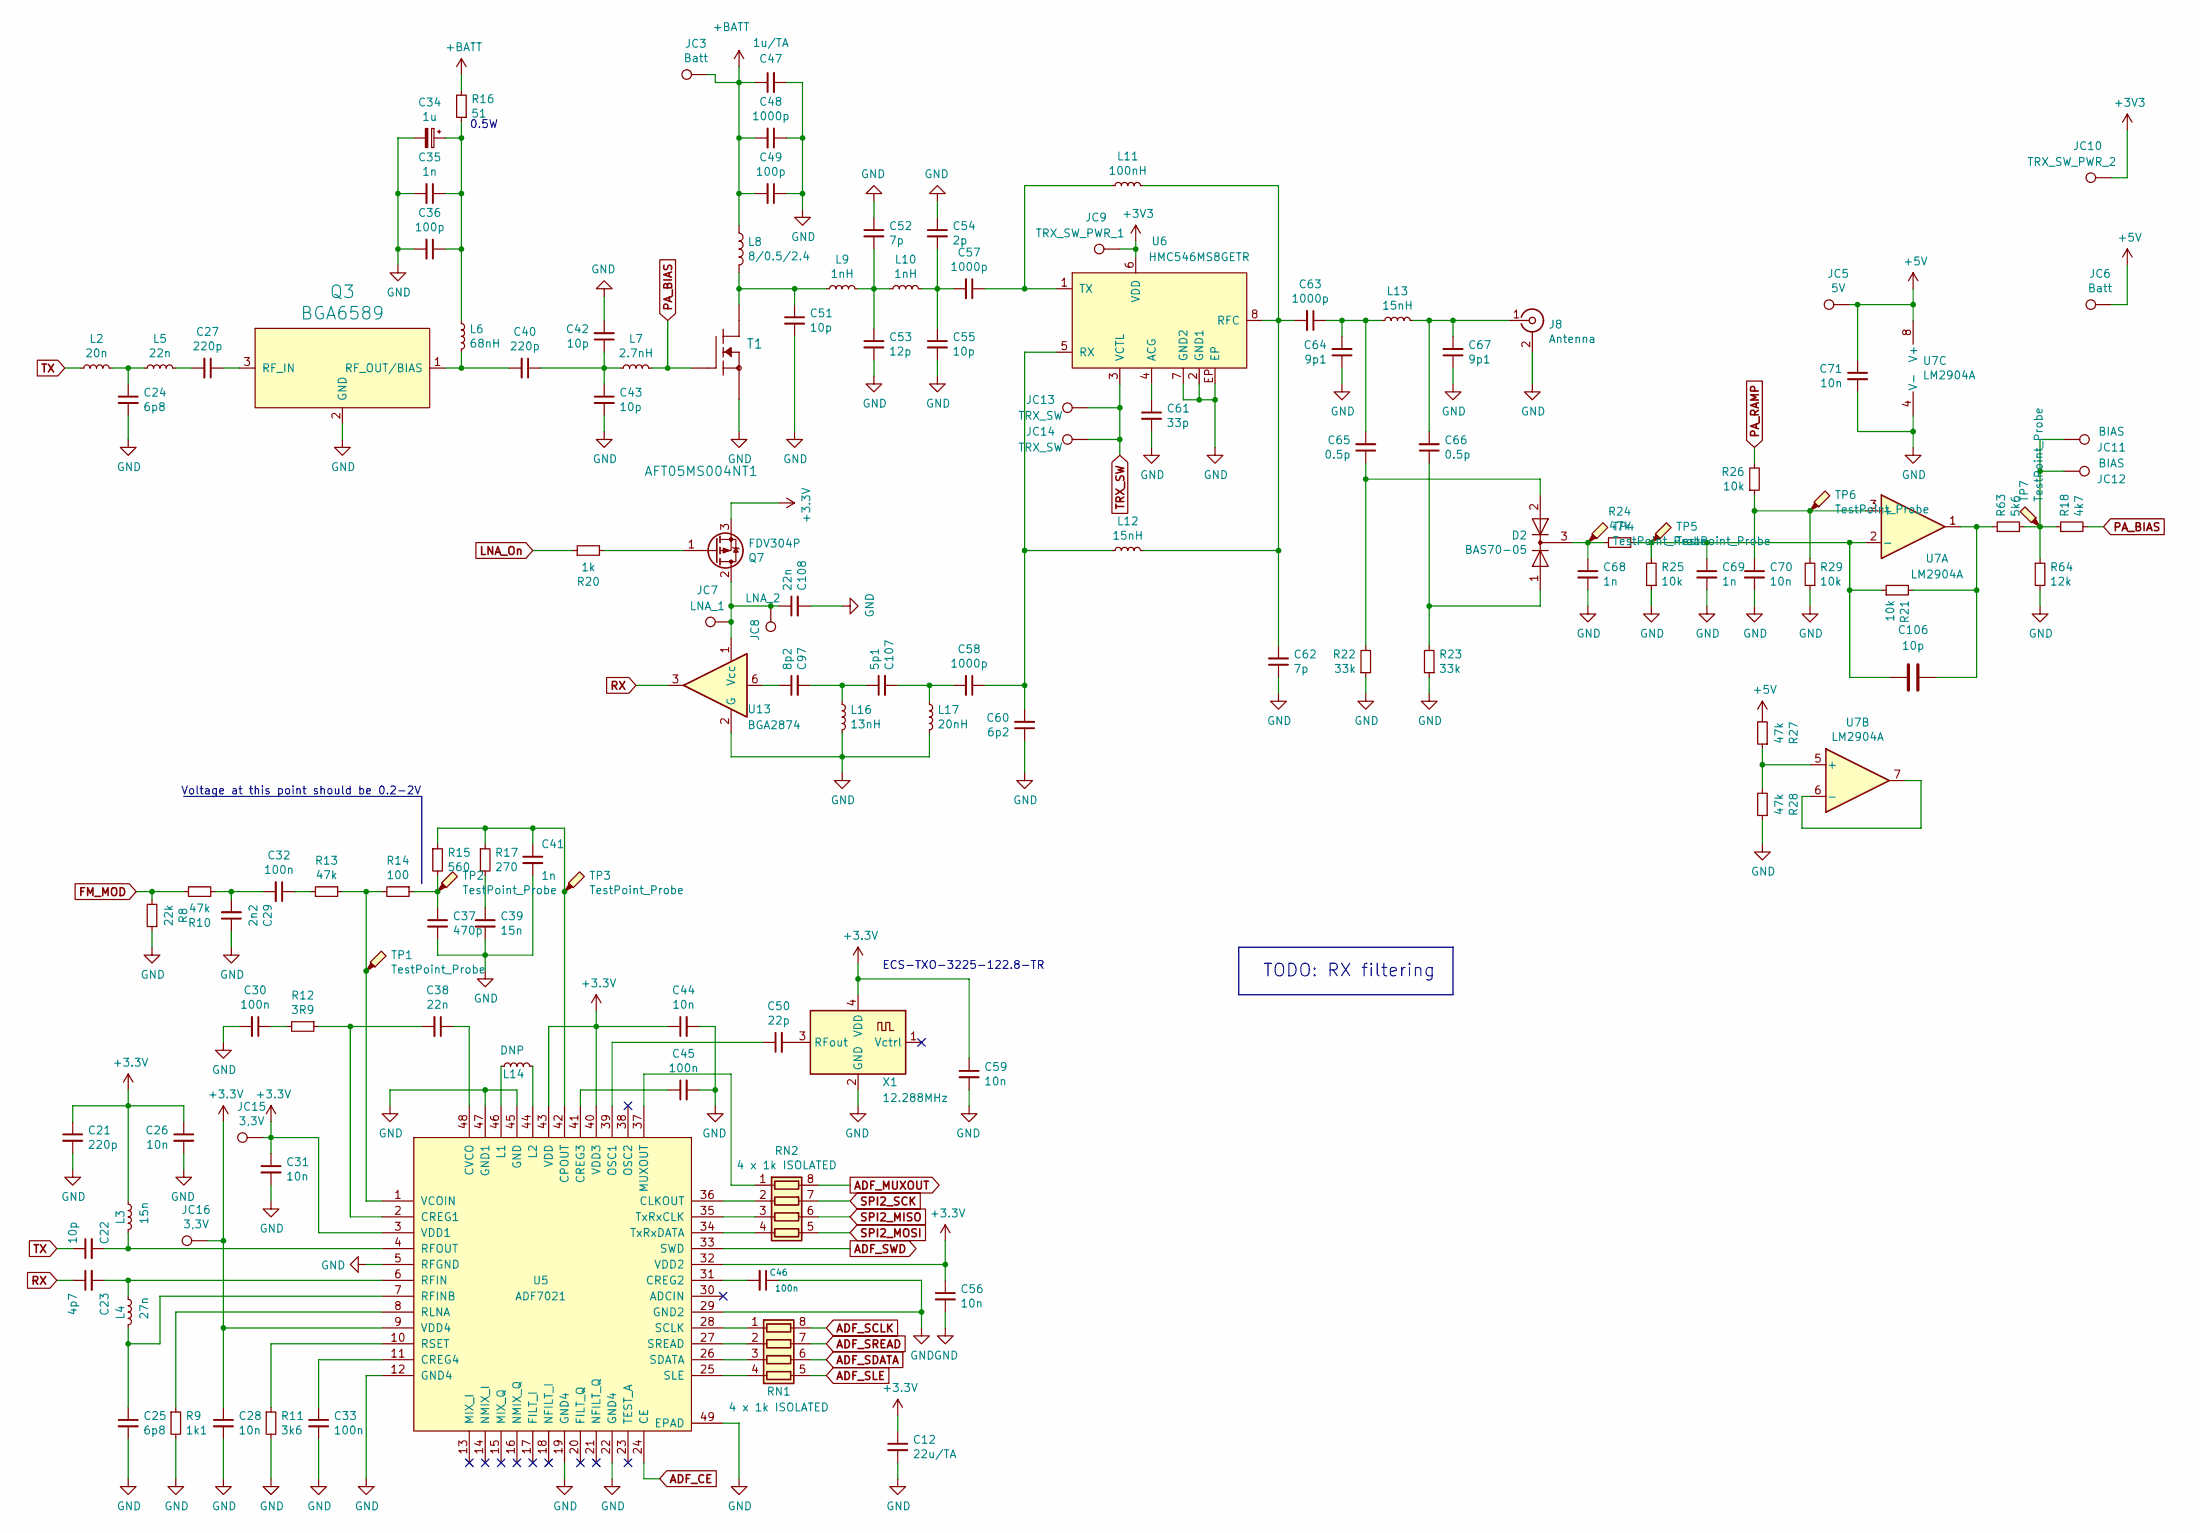
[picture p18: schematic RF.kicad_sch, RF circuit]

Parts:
C12: 22u/TA; CP_EIA-3216-18_Kemet-A; Tolerance 10; Voltage 10; Partno TAJA226K006RNJV
C21, C27, C40: 220p; C_0603_1608Metric; Voltage 50; Tolerance 5
C22, C42, C43, C51, C55: 10p; C_0603_1608Metric; Voltage 50; Tolerance 5
C23: 4p7; C_0603_1608Metric; Voltage 50; Tolerance 5
C24, C25: 6p8; C_0603_1608Metric; Voltage 50; Tolerance 5
C26, C28, C31, C44, C56, C59, C70, C71: 10n; C_0603_1608Metric; Tolerance 10; Voltage 50
C29: 2n2; C_0603_1608Metric; Voltage 50; Tolerance 5
C30, C32, C33, C45, C46: 100n; C_0603_1608Metric; Voltage 50; Tolerance 10
C34: 1u; C_0603_1608Metric; Voltage 50; Tolerance 10
C35, C41, C68, C69: 1n; C_0603_1608Metric; Voltage 50; Tolerance 10
C36, C49: 100p; C_0603_1608Metric; Voltage 50; Tolerance 5
C37: 470p; C_0603_1608Metric; Voltage 50; Tolerance 5
C38, C108: 22n; C_0603_1608Metric; Voltage 50; Tolerance 10
C39: 15n; C_0603_1608Metric; Voltage 50; Tolerance 10
C47: 1u/TA; CP_EIA-3216-18_Kemet-A; Tolerance 10; Voltage 10; Partno T491A105M016AT
C48, C57, C58, C63: 1000p; C_0603_1608Metric; Voltage 50; Tolerance 5
C50: 22p; C_0603_1608Metric; Voltage 50; Tolerance 5
C52, C62: 7p; C_0603_1608Metric; Voltage 50; Tolerance 5
C53: 12p; C_0603_1608Metric; Voltage 50; Tolerance 5
C54: 2p; C_0603_1608Metric; Voltage 50; Tolerance 5
C60: 6p2; C_0603_1608Metric; Voltage 50; Tolerance 5
C61: 33p; C_0603_1608Metric; Voltage 50; Tolerance 5
C64, C67: 9p1; C_0603_1608Metric; Voltage 50; Tolerance 5
C65, C66: 0.5p; C_0603_1608Metric; Voltage 50; Tolerance 5
C97: 8p2; C_0603_1608Metric; Voltage 50; Tolerance 5
C106: 10p
C107: 5p1; C_0603_1608Metric; Voltage 50; Tolerance 5
D2: BAS70-05; SOT-23
J8: Antenna; SMA_Samtec_SMA-J-P-X-ST-EM1_EdgeMount
JC3, JC6: Batt; Pad1x3
JC5: 5V; Pad1x3
JC7: LNA_1; Pad1x3
JC8: LNA_2; Pad1x3
JC9: TRX_SW_PWR_1; Pad1x3
JC10: TRX_SW_PWR_2; Pad1x3
JC11, JC12: BIAS; Pad1x3
JC13, JC14: TRX_SW; Pad1x3
JC15, JC16: 3,3V; TestPoint_Pad_1.0x1.0mm
L2: 20n; L_0603_1608Metric
L3: 15n; L_0603_1608Metric
L4: 27n; L_0603_1608Metric
L5: 22n; L_0603_1608Metric
L6: 68nH; L_0603_1608Metric
L7: 2.7nH; L_0603_1608Metric
L8: 8/0.5/2.4; RF_Coil_v2_mirrored
L9, L10: 1nH; L_0603_1608Metric
L11: 100nH; L_0603_1608Metric
L12, L13: 15nH; L_0603_1608Metric
L14: DNP; L_0603_1608Metric
L16: 13nH; L_0603_1608Metric
L17: 20nH; L_0603_1608Metric
Q3: BGA6589
Q7: FDV304P; SOT-23
R8: 22k; R_0603_1608Metric; Tolerance 5
R9: 1k1; R_0603_1608Metric; Tolerance 5
R10, R13, R24, R27, R28: 47k; R_0603_1608Metric; Tolerance 5
R11: 3k6; R_0603_1608Metric; Tolerance 5
R12: 3R9; R_0603_1608Metric; Tolerance 5
R14: 100; R_0603_1608Metric; Tolerance 5
R15: 560; R_0603_1608Metric; Tolerance 5
R16: 51; R_0603_1608Metric; Tolerance 5
R17: 270; R_0603_1608Metric; Tolerance 5
R18: 4k7; R_0603_1608Metric; Tolerance 5
R20: 1k; R_0603_1608Metric
R21, R25, R26, R29: 10k; R_0603_1608Metric; Tolerance 5
R22, R23: 33k; R_0603_1608Metric; Tolerance 5
R63: 5k6; R_0603_1608Metric; Tolerance 5
R64: 12k; R_0603_1608Metric; Tolerance 5
RN1, RN2: 4 x 1k ISOLATED; R_Array_Concave_4x0603; Tolerance 5
T1: AFT05MS004NT1
TP1, TP2, TP3, TP4, TP5, TP6, TP7: TestPoint_Probe; TestPoint_Pad_D1.0mm
U5: ADF7021; LFCSP-48-1EP_7x7mm_P0.5mm_EP4.1x4.1mm_ThermalVias
U6: HMC546MS8GETR
U7: LM2904A; SO-8_3.9x4.9mm_P1.27mm
U13: BGA2874; SOT-363_SC-70-6
X1: 12.288MHz; ECS-TXO-3225

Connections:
+5V: C71.1, JC5.1, JC6.1, R27.2, U7.8 (V+); also elsewhere on the board
+BATT: C47.1, C48.2, C49.2, JC3.1, L8.1, R16.2; also elsewhere on the board
ADF_CE: U5.24 (CE); also elsewhere on the board
ADF_MUXOUT: RN2.8 (R1.2); also elsewhere on the board
ADF_SCLK: RN1.8 (R1.2); also elsewhere on the board
ADF_SDATA: RN1.6 (R3.2); also elsewhere on the board
ADF_SLE: RN1.5 (R4.2); also elsewhere on the board
ADF_SREAD: RN1.7 (R2.2); also elsewhere on the board
ADF_SWD: U5.33 (SWD); also elsewhere on the board
FM_MOD: R8.2, R10.1; also elsewhere on the board
LNA_On: R20.1; also elsewhere on the board
unnamed: C22.2, L3.2, U5.4 (RFOUT)
unnamed: C23.2, L4.1, U5.6 (RFIN)
unnamed: C24.1, L2.2, L5.1
unnamed: C25.1, L4.2, U5.7 (RFINB)
unnamed: C27.1, Q3.3 (RF_IN)
unnamed: C27.2, L5.2
unnamed: C29.2, C32.2, R10.2
unnamed: C30.1, R12.2
unnamed: C32.1, R13.2
unnamed: C33.1, U5.11 (CREG4)
unnamed: C34.1, C35.1, C36.1, L6.1, R16.1
unnamed: C37.1, R14.1, R15.2, TP2.1
unnamed: C38.1, U5.48 (CVCO)
unnamed: C38.2, R12.1, U5.2 (CREG1)
unnamed: C39.1, R17.2
unnamed: C40.1, C42.1, C43.1, L7.1
unnamed: C40.2, L6.2, Q3.1 (RF_OUT/BIAS)
unnamed: C41.1, R15.1, R17.1, TP3.1, U5.42 (CPOUT)
unnamed: C45.1, U5.41 (CREG3)
unnamed: C46.2, U5.31 (CREG2)
unnamed: C50.1, U5.39 (OSC1)
unnamed: C50.2, X1.3 (RFout)
unnamed: C51.1, L8.2, L9.1, T1.D
unnamed: C52.2, C53.1, L9.2, L10.1
unnamed: C54.2, C55.1, C57.2, L10.2
unnamed: C57.1, L11.1, U6.1 (TX)
unnamed: C58.1, C60.2, L12.1, U6.5 (RX)
unnamed: C61.1, U6.4 (ACG)
unnamed: C62.2, C63.2, L11.2, L12.2, U6.8 (RFC)
unnamed: C63.1, C64.2, C65.2, L13.1
unnamed: C65.1, D2.2 (A), R22.2
unnamed: C66.1, D2.1 (A), R23.2
unnamed: C66.2, C67.2, J8.1 (In), L13.2
unnamed: C68.1, D2.3 (K), R24.2, TP4.1
unnamed: C70.1, R26.1, R29.2, TP6.1, U7.3 (+)
unnamed: C97.1, U13.6
unnamed: C106.1, R21.2, R63.1, U7.1
unnamed: C69.1, C106.2, R21.1, R24.1, R25.2, TP5.1, U7.2 (-)
unnamed: C97.2, C107.1, L16.1
unnamed: C58.2, C107.2, L17.1
unnamed: C108.1, JC7.1, JC8.1, Q7.2 (D), U13.1 (Vcc)
unnamed: JC11.1, JC12.1, R18.1, R63.2, R64.1, TP7.1
unnamed: L14.1, U5.46 (L1)
unnamed: L14.2, U5.44 (L2)
unnamed: Q7.1 (G), R20.2
unnamed: R9.1, U5.8 (RLNA)
unnamed: R11.1, U5.10 (RSET)
unnamed: R13.1, R14.2, TP1.1, U5.1 (VCOIN)
unnamed: R27.1, R28.2, U7.5 (+)
unnamed: RN1.1 (R1.1), U5.28 (SCLK)
unnamed: RN1.2 (R2.1), U5.27 (SREAD)
unnamed: RN1.3 (R3.1), U5.26 (SDATA)
unnamed: RN1.4 (R4.1), U5.25 (SLE)
unnamed: RN2.1 (R1.1), U5.37 (MUXOUT)
unnamed: RN2.2 (R2.1), U5.36 (CLKOUT)
unnamed: RN2.3 (R3.1), U5.35 (TxRxCLK)
unnamed: RN2.4 (R4.1), U5.34 (TxRxDATA)
unnamed: U7.6 (-), U7.7
PA_BIAS: L7.2, R18.2, T1.G
PA_RAMP: R26.2; also elsewhere on the board
RX: C23.1, U13.3
SPI2_MISO: RN2.6 (R3.2); also elsewhere on the board
SPI2_MOSI: RN2.5 (R4.2); also elsewhere on the board
SPI2_SCK: RN2.7 (R2.2); also elsewhere on the board
TRX_SW: JC13.1, JC14.1, U6.3 (VCTL); also elsewhere on the board
TX: C22.1, L2.1

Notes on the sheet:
Voltage at this point should be 0.2-2V
TODO: RX filtering
ECS-TXO-3225-122.8-TR
0.5W

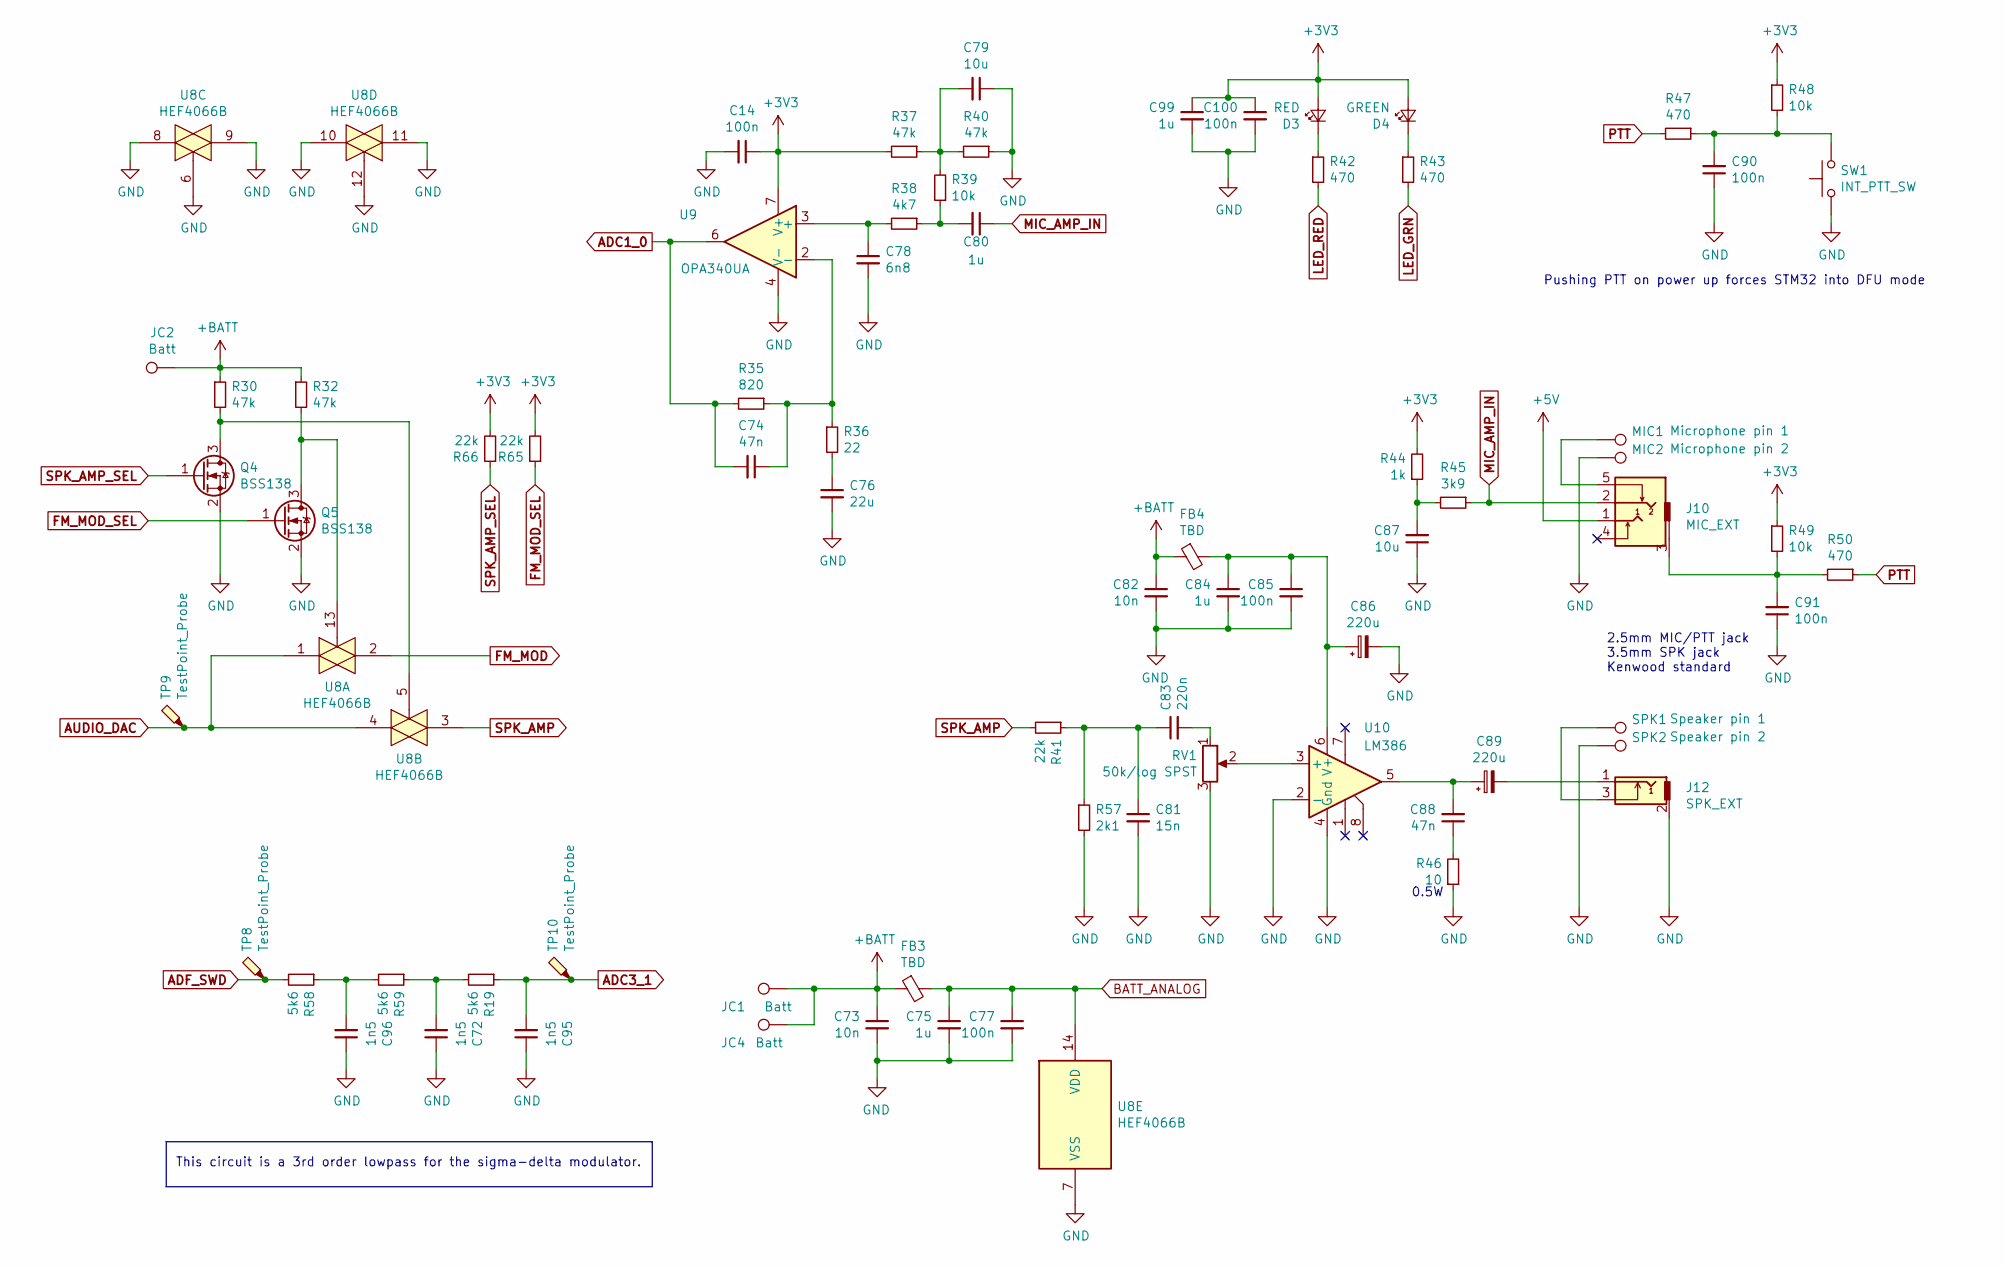
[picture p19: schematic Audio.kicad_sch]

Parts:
C14, C77, C85, C90, C91, C100: 100n; C_0603_1608Metric; Voltage 50; Tolerance 10
C72, C95, C96: 1n5; C_0603_1608Metric; Voltage 50; Tolerance 10
C73, C82: 10n; C_0603_1608Metric; Tolerance 10; Voltage 50
C74, C88: 47n; C_0603_1608Metric; Voltage 50; Tolerance 10
C75, C80, C84, C99: 1u; C_0603_1608Metric; Voltage 50; Tolerance 10
C76: 22u; C_0603_1608Metric; Voltage 10; Tolerance 10
C78: 6n8; C_0603_1608Metric; Voltage 50; Tolerance 10
C79, C87: 10u; C_0603_1608Metric; Voltage 10; Tolerance 10
C81: 15n; C_0603_1608Metric; Voltage 50; Tolerance 10
C83: 220n; C_0603_1608Metric; Voltage 50; Tolerance 10
C86, C89: 220u; CP_EIA-7343-31_Kemet-D; Tolerance 10; Voltage 10; Partno TCJD227M016R0050
D3: RED; D_0603_1608Metric
D4: GREEN; D_0603_1608Metric
FB3, FB4: TBD; L_0603_1608Metric
J10: MIC_EXT
J12: SPK_EXT
JC1, JC2, JC4: Batt; Pad1x3
MIC1: Microphone pin 1; TestPoint_Pad_2.0x2.0mm
MIC2: Microphone pin 2; TestPoint_Pad_2.0x2.0mm
Q4, Q5: BSS138; SOT-23
R19, R58, R59: 5k6; R_0603_1608Metric; Tolerance 5
R30, R32, R37, R40: 47k; R_0603_1608Metric; Tolerance 5
R35: 820; R_0603_1608Metric; Tolerance 5
R36: 22; R_0603_1608Metric; Tolerance 5
R38: 4k7; R_0603_1608Metric; Tolerance 5
R39, R48, R49: 10k; R_0603_1608Metric; Tolerance 5
R41, R65, R66: 22k; R_0603_1608Metric; Tolerance 5
R42, R43, R47, R50: 470; R_0603_1608Metric; Tolerance 5
R44: 1k; R_0603_1608Metric; Tolerance 5
R45: 3k9; R_0603_1608Metric; Tolerance 5
R46: 10; R_0603_1608Metric; Tolerance 5
R57: 2k1; R_0603_1608Metric; Tolerance 5
RV1: 50k/log SPST; PinHeader_1x03_P1.27mm_Vertical; Partno Alps RK0971111Z32
SPK1: Speaker pin 1; TestPoint_Pad_2.0x2.0mm
SPK2: Speaker pin 2; TestPoint_Pad_2.0x2.0mm
SW1: INT_PTT_SW; SW_Push_1P1T_NO_CK_KMR2
TP8, TP9, TP10: TestPoint_Probe; TestPoint_Pad_D1.0mm
U8: HEF4066B; SOIC-14_3.9x8.7mm_P1.27mm
U9: OPA340UA; SO-8_3.9x4.9mm_P1.27mm
U10: LM386; SOIC-8_3.9x4.9mm_P1.27mm

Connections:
+5V: J10.1; also elsewhere on the board
+BATT: C73.1, C82.1, FB3.1, FB4.1, JC1.1, JC2.1, JC4.1, R30.1, R32.1; also elsewhere on the board
ADC1_0: C74.2, R35.2, U9.6; also elsewhere on the board
ADC3_1: C95.2, R19.1, TP10.1; also elsewhere on the board
ADF_SWD: R58.2, TP8.1; also elsewhere on the board
AUDIO_DAC: TP9.1, U8.1, U8.4; also elsewhere on the board
BATT_ANALOG: C75.1, C77.1, FB3.2, U8.14 (VDD)
FM_MOD: U8.2; also elsewhere on the board
FM_MOD_SEL: Q5.1 (G), R65.1; also elsewhere on the board
LED_GRN: R43.2; also elsewhere on the board
LED_RED: R42.2; also elsewhere on the board
MIC_AMP_IN: C80.1, J10.2, R45.1
unnamed: C72.2, R19.2, R59.1
unnamed: C74.1, R35.1, R36.1, U9.2 (-)
unnamed: C76.1, R36.2
unnamed: C78.1, R38.2, U9.3 (+)
unnamed: C79.2, R37.1, R39.2, R40.2
unnamed: C80.2, R38.1, R39.1
unnamed: C81.1, C83.1, R41.1, R57.1
unnamed: C83.2, RV1.1
unnamed: C84.1, C85.1, C86.1, FB4.2, U10.6 (V+)
unnamed: C87.2, R44.1, R45.2
unnamed: C88.1, R46.2
unnamed: C88.2, C89.1, U10.5
unnamed: C89.2, J12.1
unnamed: C91.2, J10.3, R49.2, R50.2
unnamed: C96.2, R58.1, R59.2
unnamed: D3.1 (K), R42.1
unnamed: D4.1 (K), R43.1
unnamed: J10.5, MIC1.1
unnamed: J12.3, SPK1.1
unnamed: Q4.3 (D), R30.2, U8.5
unnamed: Q5.3 (D), R32.2, U8.13
unnamed: RV1.2, U10.3 (+)
PTT: R47.2, R50.1; also elsewhere on the board
SPK_AMP: R41.2, U8.3
SPK_AMP_SEL: Q4.1 (G), R66.1; also elsewhere on the board

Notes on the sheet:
This circuit is a 3rd order lowpass for the sigma-delta modulator.
2.5mm MIC/PTT jack 3.5mm SPK jack Kenwood standard
Pushing PTT on power up forces STM32 into DFU mode
0.5W

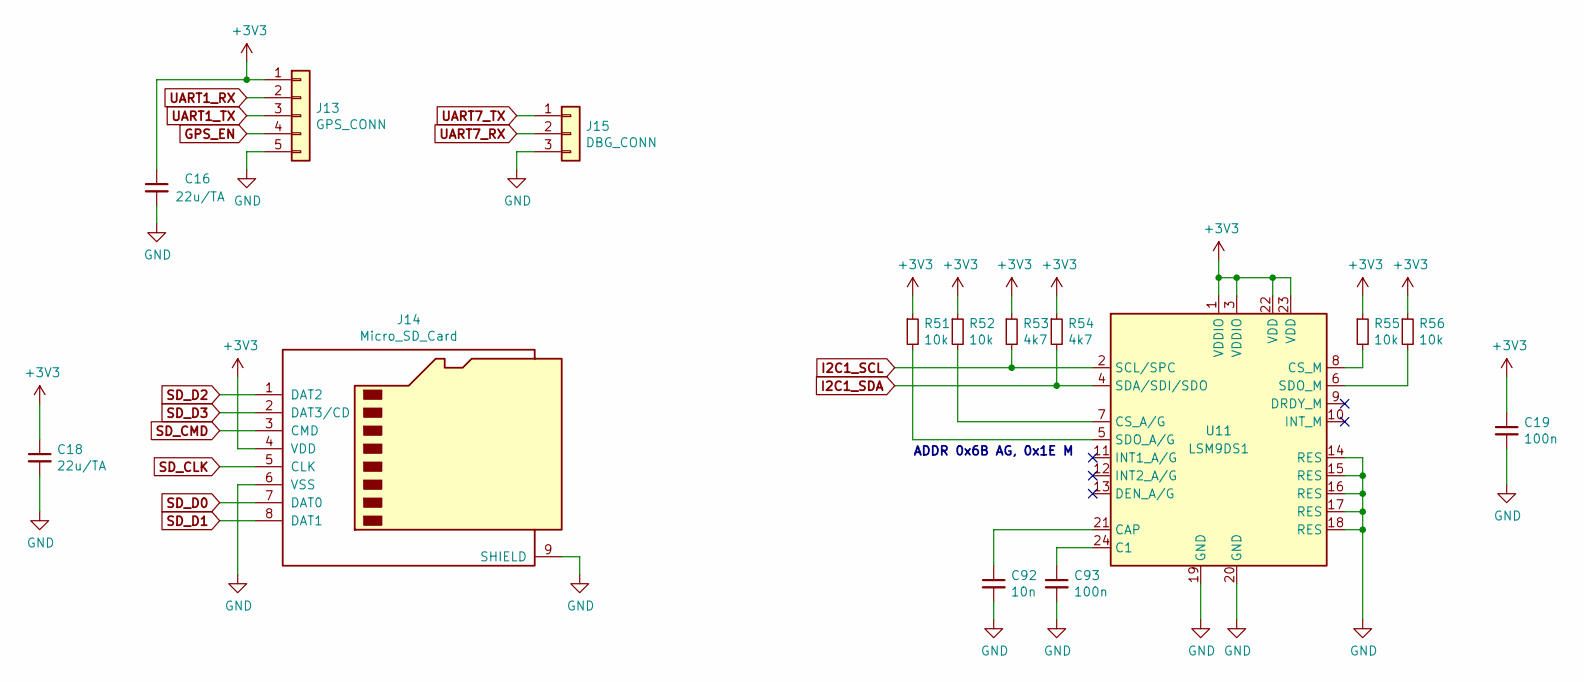
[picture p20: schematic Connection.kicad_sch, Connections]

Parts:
C16, C18: 22u/TA; CP_EIA-3216-18_Kemet-A; Tolerance 10; Voltage 10; Partno TAJA226K006RNJV
C19, C93: 100n; C_0603_1608Metric; Voltage 50; Tolerance 10
C92: 10n; C_0603_1608Metric; Tolerance 10; Voltage 50
J13: GPS_CONN; PinHeader_1x05_P1.27mm_Vertical
J14: Micro_SD_Card; microSD; Partno AdamTech MCSP-Q1-08-A-SG
J15: DBG_CONN; PinHeader_1x03_P1.27mm_Vertical
R51, R52, R55, R56: 10k; R_0603_1608Metric; Tolerance 5
R53, R54: 4k7; R_0603_1608Metric; Tolerance 5
U11: LSM9DS1; LGA-24L_3x3.5mm_P0.43mm

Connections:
GPS_EN: J13.4; also elsewhere on the board
I2C1_SCL: R53.2, U11.2 (SCL/SPC); also elsewhere on the board
I2C1_SDA: R54.2, U11.4 (SDA/SDI/SDO); also elsewhere on the board
unnamed: C92.1, U11.21 (CAP)
unnamed: C93.1, U11.24 (C1)
unnamed: R51.2, U11.5 (SDO_A/G)
unnamed: R52.2, U11.7 (CS_A/G)
unnamed: R55.2, U11.8 (CS_M)
unnamed: R56.2, U11.6 (SDO_M)
SD_CLK: J14.5 (CLK); also elsewhere on the board
SD_CMD: J14.3 (CMD); also elsewhere on the board
SD_D0: J14.7 (DAT0); also elsewhere on the board
SD_D1: J14.8 (DAT1); also elsewhere on the board
SD_D2: J14.1 (DAT2); also elsewhere on the board
SD_D3: J14.2 (DAT3/CD); also elsewhere on the board
UART1_RX: J13.2; also elsewhere on the board
UART1_TX: J13.3; also elsewhere on the board
UART7_RX: J15.2; also elsewhere on the board
UART7_TX: J15.1; also elsewhere on the board

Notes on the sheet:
ADDR 0x6B AG, 0x1E M

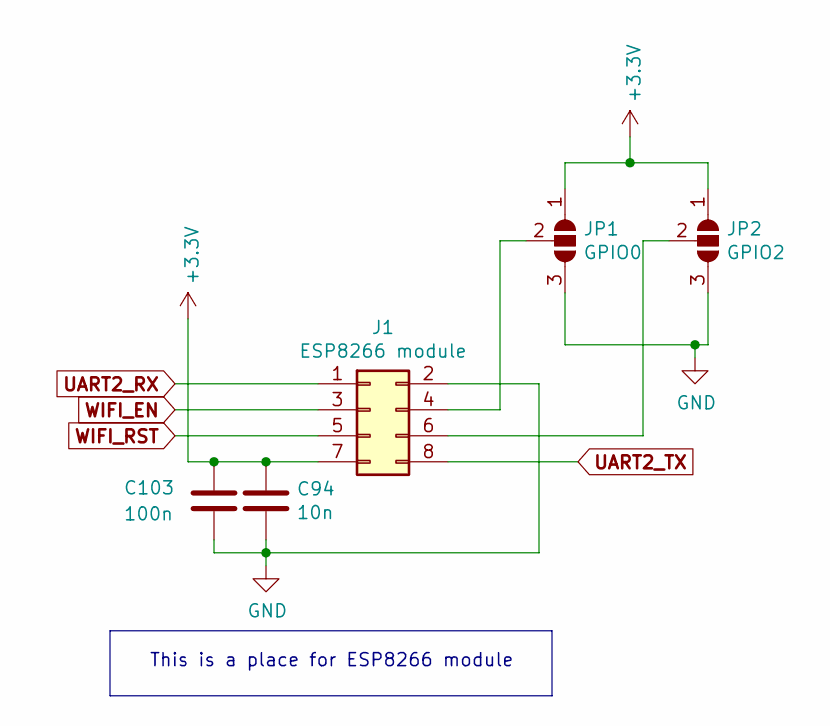
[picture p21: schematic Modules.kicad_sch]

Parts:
C94: 10n; C_0603_1608Metric; Tolerance 10; Voltage 50
C103: 100n; C_0603_1608Metric; Voltage 50; Tolerance 10
J1: ESP8266 module; PinHeader_2x04_P2.54mm_Vertical
JP1: GPIO0; SolderJumper-3_P1.3mm_Open_RoundedPad1.0x1.5mm
JP2: GPIO2; SolderJumper-3_P1.3mm_Open_RoundedPad1.0x1.5mm

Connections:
unnamed: J1.4, JP1.2 (C)
unnamed: J1.6, JP2.2 (C)
UART2_RX: J1.1; also elsewhere on the board
UART2_TX: J1.8; also elsewhere on the board
WIFI_EN: J1.3; also elsewhere on the board
WIFI_RST: J1.5; also elsewhere on the board

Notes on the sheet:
This is a place for ESP8266 module

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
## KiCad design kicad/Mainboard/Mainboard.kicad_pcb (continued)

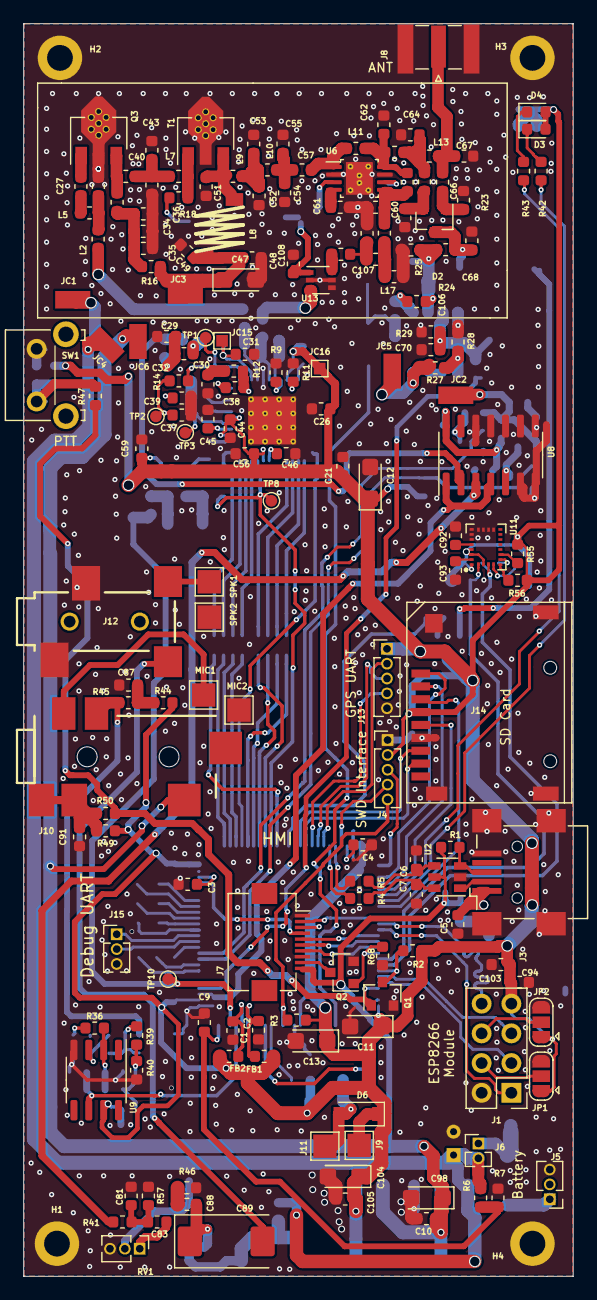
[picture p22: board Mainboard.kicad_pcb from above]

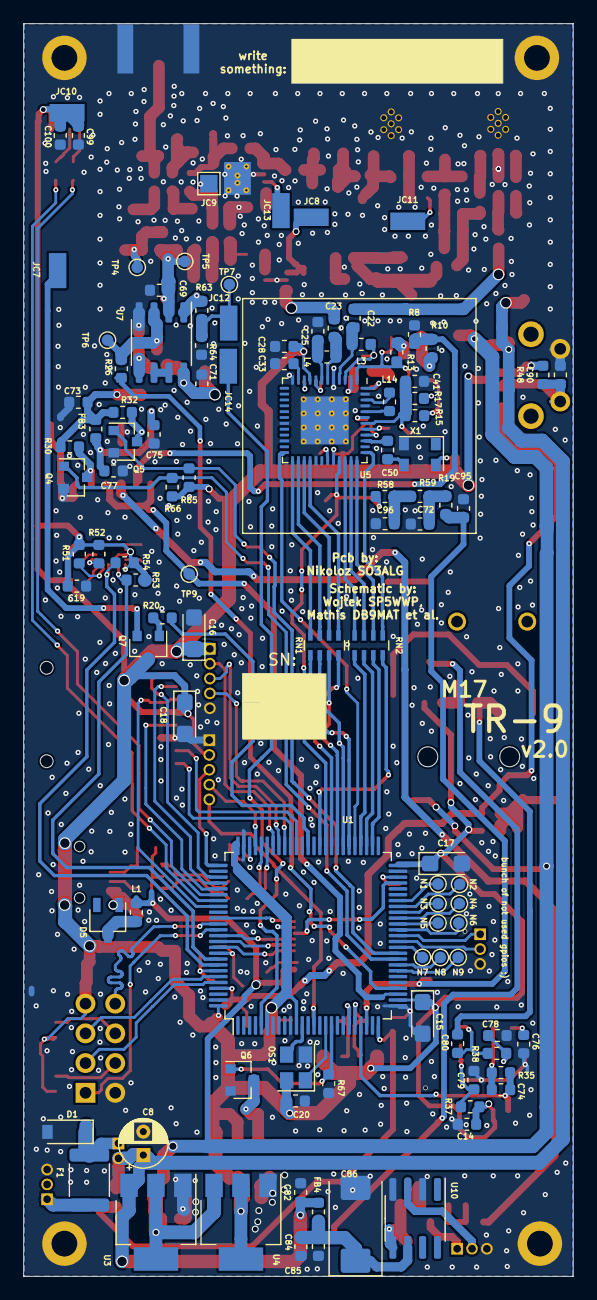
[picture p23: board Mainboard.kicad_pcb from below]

Board: 2 copper layers, 47.0 x 107.1 mm, 279 parts (105 on the bottom side), 177 nets.

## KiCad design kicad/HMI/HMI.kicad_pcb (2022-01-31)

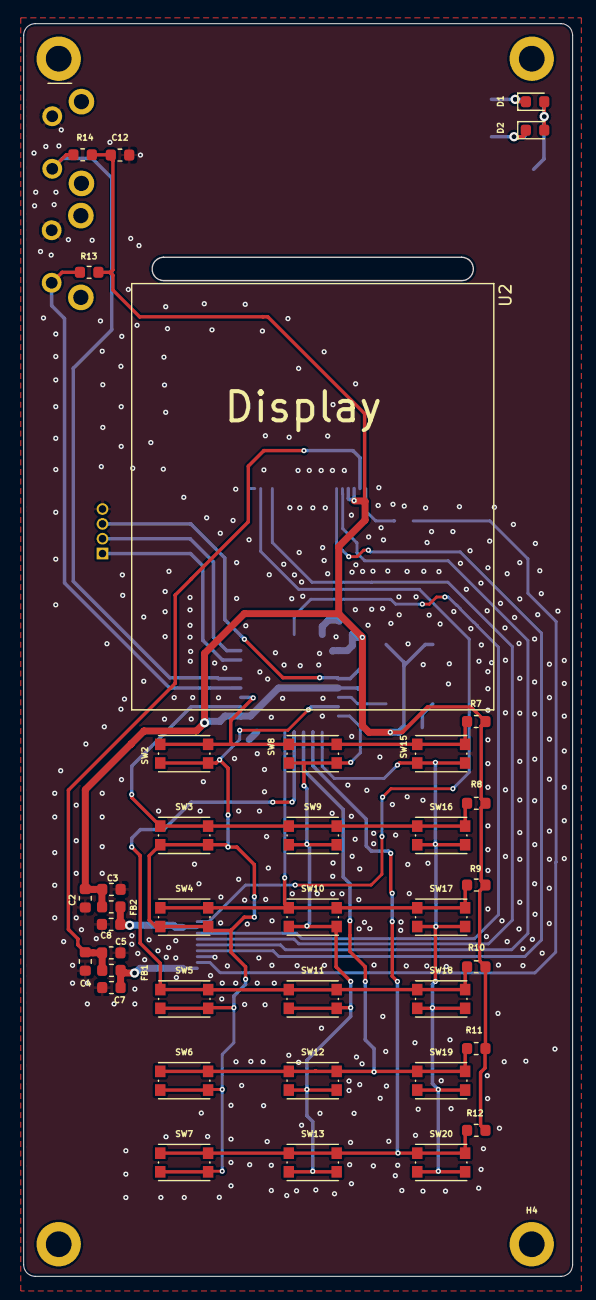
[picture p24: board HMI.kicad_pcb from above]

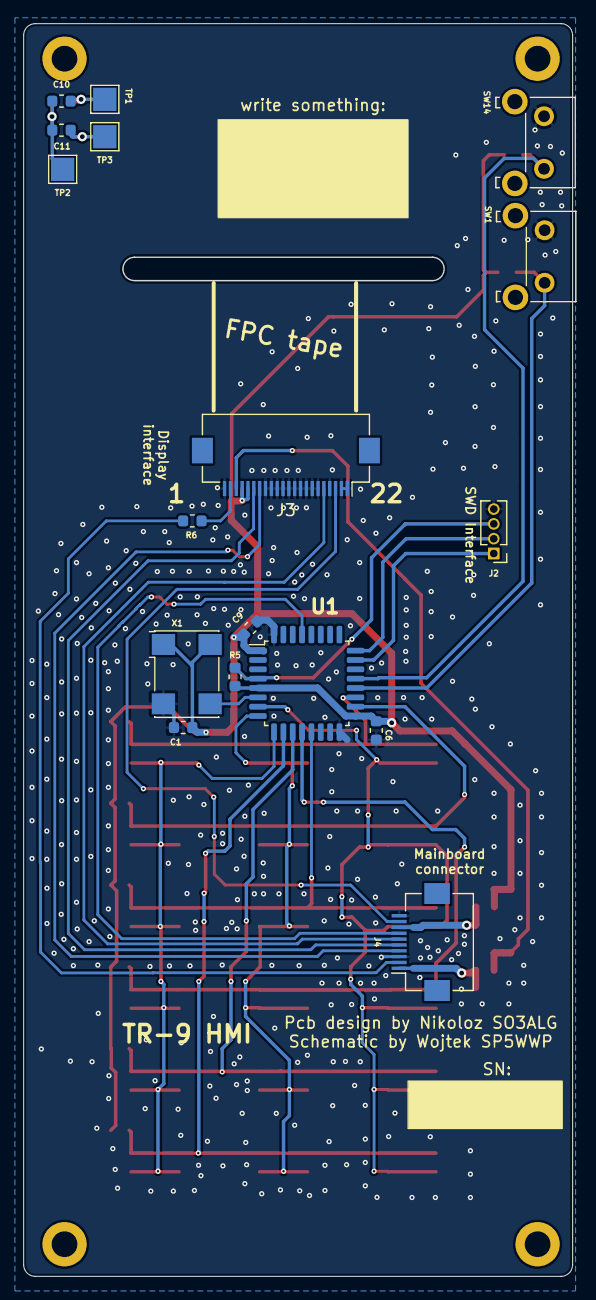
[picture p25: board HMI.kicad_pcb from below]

Board: 2 copper layers, 47.0 x 107.2 mm, 59 parts (17 on the bottom side), 30 nets.

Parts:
C1: 10n; C_0603_1608Metric
C2, C4, C7, C8, C10, C11: 100n; C_0603_1608Metric
C3, C5, C6, C9, C12: 1u; C_0603_1608Metric
D1, D2: LED; D_0603_1608Metric
FB1, FB2: Ferrite_Bead; L_0603_1608Metric
H1, H2, H3, H4: M2; MountingHole_2.2mm_M2_ISO14580_Pad
J2: SWD; PinHeader_1x04_P1.27mm_Vertical
J3: FH12-22S-0.5SH; Hirose_FH12-22S-0.5SH_1x22-1MP_P0.50mm_Horizontal
J4: RIBBON; Hirose_FH12-10S-0.5SH_1x10-1MP_P0.50mm_Horizontal
R5: 10k; R_0603_1608Metric
R6: 47R; R_0603_1608Metric
R7, R8, R9, R10, R11, R12, R13, R14: 47k; R_0603_1608Metric
SW1, SW14: SW_Push; SW_Tactile_SKHH_Angled
SW2, SW3, SW4, SW5, SW6, SW7, SW8, SW9, SW10, SW11, SW12, SW13, SW15, SW16, SW17, SW18, SW19, SW20: SW_Push; SW_Push_1P1T_NO_CK_KMR2
TP1, TP2, TP3: TestPoint; TestPoint_Pad_2.0x2.0mm
U1: STM32L011K4Tx; LQFP-32_7x7mm_P0.8mm
U2: DEM 128128A TMH-PW-N; DEM_128128A_TMH-PW-N
X1: ASV-4.000MHZ-EJ-T; Oscillator_SMD_Abracon_ASV-4Pin_7.0x5.1mm

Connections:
+3V3: C1.1, C2.1, C3.1, C6.1, C9.1, C12.1, FB2.2, J3.18, J3.19, R5.1, R7.1, R8.1, R9.1, R10.1, R11.1, R12.1, R13.1, R14.1, U1.1, U1.5, U1.17, X1.1, X1.4
+5V: C4.1, C5.1, FB1.2, J3.20
C1: SW2.2, SW3.2, SW4.2, SW5.2, SW6.2, SW7.2, U1.7
C2: SW8.2, SW9.2, SW10.2, SW11.2, SW12.2, SW13.2, U1.8
C3: SW15.2, SW16.2, SW17.2, SW18.2, SW19.2, SW20.2, U1.9
F1: R13.2, SW1.2, U1.20
F2: R14.2, SW14.2, U1.21
GND: C1.2, C2.2, C3.2, C4.2, C5.2, C6.2, C7.2, C8.2, C9.2, C12.2, J2.4, J3.1, J3.2, J3.4, J3.6, J3.7, J3.8, J3.9, J3.10, J3.11, J3.12, J3.13, J3.14, J3.15, J3.22, J4.3, J4.10, SW1.1, SW14.1, U1.16, U1.32, X1.2
NRST: J2.3, R5.2, U1.4
unnamed: C7.1, FB1.1, J4.1
unnamed: C8.1, FB2.1, J4.8
unnamed: C10.1, C11.1, D1.2, D2.2, TP2.1
unnamed: C10.2, D1.1, TP1.1
unnamed: C11.2, D2.1, TP3.1
unnamed: J3.21, R6.2
OSC: U1.6, X1.3
R1: R12.2, SW7.1, SW13.1, SW20.1, U1.10
R2: R11.2, SW6.1, SW12.1, SW19.1, U1.11
R3: R10.2, SW5.1, SW11.1, SW18.1, U1.12
R4: R9.2, SW4.1, SW10.1, SW17.1, U1.13
R5: R8.2, SW3.1, SW9.1, SW16.1, U1.18
R6: R7.2, SW2.1, SW8.1, SW15.1, U1.19
SPI1_CS: J3.16, J4.4
SPI1_MOSI: J3.5, J4.6
SPI1_SCK: J3.17, J4.5
SWCLK: J2.2, U1.24
SWDIO: J2.1, U1.23
TFT_LED: J4.2, R6.1
TFT_RST: J3.3, J4.9
TX: J4.7, U1.29

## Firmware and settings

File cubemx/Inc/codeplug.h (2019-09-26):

/*
 * codeplug.h
 *
 *  Created on: 14.12.2018
 *      Author: SP5WWP
 */

#ifndef CODEPLUG_H_
#define CODEPLUG_H_

#define MAX_CHANNELS_PER_BANK			20			//max channels allowed in a bank
#define MAX_NAME_LEN					12+1		//max text length (except for VERSION -> 20)
#define MAX_BANK_NUM					100			//maximum bank number

#define K_AUTHOR						"author"
#define AUTHOR							1
#define K_VERSION						"version"
#define VERSION							2

#define K_NUM_BANKS						"num_banks"
#define NUM_BANKS						3
#define K_NUM							"num"
#define NUM								4
#define K_NAME							"name"
#define NAME							5
#define K_NUM_CHANNELS					"num_channels"
#define NUM_CHANNELS					6
#define K_DESCR							"descr"
#define DESCR							7
#define K_FREQ_RX						"freq_rx"
#define FREQ_RX							81
#define K_FREQ_TX						"freq_tx"
#define FREQ_TX							82
#define K_ENCR							"encr"
#define ENCR							9
#define K_GPS							"gps"
#define GPS								10

#define EMPTY_OR_COMMENT				255

#define K_CODEPLUG						"codeplug"
#define CODEPLUG						100
#define K_BANK							"bank"
#define BANK							101
#define K_CHANNEL						"channel"
#define CHANNEL							102
#define K_END							"end"
#define END								200

#endif /* CODEPLUG_H_ */

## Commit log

2019-01-27 Add files via upload
    I have probably finally fixed interrupt priorities :) also - PTT action is now interrupt driven
2019-12-26 Initial WIP KiCAD schematics
    Initial commit of the schematics redrawn in KiCAD with some fixes applied. Still needs to be cleaned up
    [Audio.sch, Connection.sch, Mainboard.kicad_pcb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]
2019-12-26 Removed Eagle files
    Transitioning from Eagle to KiCAD
    [disp.brd, disp.sch, kbd.brd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]
2019-12-27 Added power detector
    Added two missing inductors in the RF output switch and started work on the power detection circuit
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2020-01-14 Add files via upload
    * replaced Q7 with BSS138
    * new HMI connector (for keypad and display)
    [Audio.sch, Connection.sch, Mainboard.sch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]
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2020-01-22 Add files via upload
    replaced TCXO with ECS-TXO-3225-122.8-TR
    [RF.sch]
2020-01-22 Add files via upload
    added 2 buttons: F1 and F2
    [HMI.sch]
2020-01-27 Add files via upload
    added a resistor to form a voltage divider network (at pin 3 of LM2904) and changed the cap from 100n to 10n
    [RF.sch]
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2020-01-28 Revert "Annotated parts"
    This reverts commit b309e3bfe0d7a41f96c10818008ed221b92f9604.
    [Audio.sch, Connection.sch, RF.sch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]
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2020-02-01 Add files via upload
    ADF7021 pin 36: SPI1_SCK -> SPI2_SCK
    [Audio.sch, Connection.sch, Mainboard.sch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]
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2020-02-04 Add files via upload
    added a Sallen-Key 6kHz anti-aliasing lowpass filter between the ADF (SWD pin) and STM32 (ADC input)
    [Audio.sch]
2020-02-08 Add files via upload
    assigned some more footprints
    [Audio.sch, Connection.sch, Modules.sch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]
2020-02-09 Add files via upload
    fixed U7 name (LM2904A)
    [Audio.sch, RF.sch]
2020-02-13 - Added footprint library - TR-9 - Imported a few footprints - Designed a MicroSD card slot footprint - Assignment footprints to corresponding elements on schematic
    [Audio.sch, Connection.sch, Mainboard.sch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]
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2020-02-13 - designed and added footprint for L8 RF inductor
    [Connection.sch, RF.sch, STM32.sch]
2020-02-13 Added HMC RF switch Corrected SOIC footprints assignment
    [Audio.sch, PSU.sch, RF.sch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]
2020-02-14 Added thermal vias to BGA6589 footprint Corrected USART to UART
    [Connection.sch, Mainboard.kicad_pcb, Modules.sch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]
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2020-02-14 started working on PCB - power supply completed plotted new PDF schematic
    [Audio.sch, Connection.sch, Mainboard.kicad_pcb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]
2020-02-14 added a capacitor for GPS voltage line footprints - expanded RF transistors ground plane generated new PDF added authors
    [Audio.sch, Connection.sch, Mainboard.kicad_pcb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]
2020-02-15 Add files via upload
    i've set some footprints and changed that 10-pin connector pin order
    [HMI.sch]
2020-02-15 PCB - connected microSD card to STM32 & USB frontend path routed added a schottky diode PMEG4005ET.215 footprint changed connector J7 pinout - TFT_RST swapped with UART2_RX! schootky diode added to i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
    [Audio.sch, Connection.sch, Mainboard.kicad_pcb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]
2020-02-15 Corrected outline in PCB
    [Mainboard.kicad_pcb]
2020-02-15 another pin swap
    [HMI.sch]
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2020-02-16 Module with OPA340UA U9 made smaller - more space for other modules
    [Mainboard.kicad_pcb]
2020-02-16 Power supply part occupies less space on pcb!
    [Mainboard.kicad_pcb]
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2020-02-18 Critical J7 header pinout change! New schematic PCB plot
    [Audio.sch, Connection.sch, Mainboard.kicad_pcb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]
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2020-02-19 smaller RF Power part + diode pins swap + PLOT PDF
    [Audio.sch, Connection.sch, Mainboard.kicad_pcb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]
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2020-02-20 added vibration motor
    [Audio.sch, Connection.sch, Mainboard.sch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]
2020-02-20 RF path improvement, changing speaker and microphone headers to soldering pads, plotting new PDF
    [Audio.sch, Connection.sch, Mainboard.kicad_pcb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]
2020-02-20 pin correct
    [Mainboard.kicad_pcb]
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2020-02-22 RF power amp, and RF chipset on pcb
    [Audio.sch, Connection.sch, Mainboard.kicad_pcb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]
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2020-02-23 Power lines spread around the pcb, kenwood connector(2 jacks), J4 and J13 placed in better place
    [Mainboard.kicad_pcb]
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2020-02-24 Shielding outline correction, and etc...
    [Mainboard.kicad_pcb]
2020-02-25 started to reorganize an elements - further optimisation
    [Mainboard.kicad_pcb]
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2020-02-26 UART3 swapped with UART2 - now keyboard uses UART3, and WIFI uses UART2; added ladder for ADF7021 data lines; further pcb improvement(shielding for ADF7021 part)
    [Mainboard.kicad_pcb, Modules.sch, RF.sch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]
2020-02-26 correction on schematic - UART3 with UART2 swap; new PDF plot further pcb improvement
    [Mainboard.kicad_pcb, STM32.sch]
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2020-02-29 Added 2,4GHz antenna; added RF matching Pi circuit; plotted new PDF
    [Mainboard.kicad_pcb, Modules.sch]
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2020-03-01 Drawn meanders for flash memory of ESP32 chip. trace difference max +- 0,2mm Added status diodes
    [Mainboard.kicad_pcb]
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2020-03-02 corrected FPC footprint assignment
    [HMI.sch]
2020-03-03 added SWD pins to the micro, started laying out the board
    [HMI.sch]
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2020-03-06 HMI - changed SW1 and SW14 button footprint; Mainboard - further changes; TR-9 library, correcting footprint
    [HMI.kicad_pcb, HMI.sch, Mainboard.kicad_pcb]
2020-03-23 changed Sallen-Key filter RC values (to 6.8k and 2.2n)
    [Audio.sch, Connection.sch, Mainboard.sch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]
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2020-05-02 added BGA2874 RX amplifier & highpass LC filter(schematic & pcb) pcb design nearly done ~95%
    [Audio.sch, Connection.sch, Mainboard.kicad_pcb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]
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2020-05-16 added RF switch on-off transistor, plotted new schematic
    [Mainboard.kicad_pcb, RF.sch, STM32.sch]
2020-05-18 fixed p-mos alignment :)
    [Audio.sch, Connection.sch, Mainboard.sch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]
2020-05-31 Added some vias and forgotten power supply lines & plotted pdf schematic
    [Audio.sch, Connection.sch, Mainboard.kicad_pcb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]
2020-06-10 added vias, and long soldering pads(for shielding) around RF Amplifier part, added more vias near STM32, added 3D visualizaton of PCB!
    [Mainboard.kicad_pcb, RF.sch]
2020-06-11 added 9 TestPoints called N1 ... to N9, which allow to debug STM32, and experiment with more peripherals in the future. Plotted PDF schematic
    [Mainboard.kicad_pcb, STM32.sch]
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2020-06-27 added a JCx symbols - these are Jumper Cables - them are used to avoid EMI diseaster when trying to route Power signals under RF 50 ohm trace - also added them to PCB + Schematic in PDF plotted; TODO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
    [Audio.sch, Mainboard.kicad_pcb, RF.sch]
2020-07-05 few fixes
    [Mainboard.kicad_pcb]
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2020-07-08 removed ESP8266 and it's circuitry; instead added a Pin Headers 2x4 for soldering in ESP8266 SoM; changed vias to manufacturable by JlcPcb; plotted PDF
    [Mainboard.kicad_pcb, Modules.sch, RF.sch]
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2020-07-11 more changes on RF chipset - adding jumperpoint 15&16
    [Mainboard.kicad_pcb, RF.sch]
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2020-07-13 added jumpers on GPIO0 and GPIO2 for ESP8266 module; described pin headers on PCB; connected pin 16 of STM32 to Power Down pin in OS1; plotted schematic in PDF
    [Mainboard.kicad_pcb, Modules.sch, STM32.sch]
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2020-07-14 informations about connectors on PCB; more vias for better signal integrity; new pcb 3D photos
    [Mainboard.kicad_pcb]
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2020-07-15 added Jumper cable connections description -> moved "M17" and "TR-9" labels -> added label "v 2.0" -> plotted PDF
    [Mainboard.kicad_pcb, Mainboard.sch]
2020-07-15 changed OscillatorON to XO_EN -> added "SN:" title on PCB -> plotted new PDF
    [Mainboard.kicad_pcb, STM32.sch]
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2020-07-22 HMI: added design of PCB -> plotted PDF -> plotted production output - Gerbers -> HMI is READY!!
    [HMI-B_Cu.gbr, HMI-B_Mask.gbr, HMI-B_Paste.gbr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]
2020-07-22 Mainboard: plotted PDF -> added design of PCB -> plotted Gerbers -> Mainboard ready!
    [Audio.sch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]
2020-07-26 Added missing 3D models
    [FH12-22S-0.5SH.step, HMI.kicad_pcb, Mainboard.kicad_pcb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]
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2020-07-29 Mainboard: List of components -> Added TempCoef types, voltage values and tolerance for capaciors; added power values and tolerance for resistors
    [Audio.sch, Connection.sch, Modules.sch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]
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2020-07-30 HMI -> corrected PCB to mainboard form factor, added diodes
    [HMI.kicad_pcb, HMI.sch]
2020-07-31 Generated Gerbers for new HMI, corrected BOM for Mainboard
    [Audio.sch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]
2020-07-31 HMI: widened space between keys on keypad -> generated new Gerbers & STEP
    [HMI-B_Cu.gbr, HMI-B_Mask.gbr, HMI-B_Paste.gbr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]
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2020-08-01 HMI: Added space over display + Mainboard connector placement correction -> Generated GERBER + STEP + 3D visualisation
    [HMI-B_Cu.gbr, HMI-B_Mask.gbr, HMI-B_Paste.gbr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]
2020-08-02 HMI: added labels on silksScreen -> added one capacitor -> generated new PDF -> generated new GERBERS -> NEW STEP!
    [HMI-B_Cu.gbr, HMI-B_Mask.gbr, HMI-B_Paste.gbr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]
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2020-09-13 Mainboard: corrected C47 & properly described C76, C79, C87 & assigned value to R20 & L1 is now Fair-Rite 2506032217Y2 & Volume pot is now Alps RK0971111Z32
    [Audio.sch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]
2020-10-12 Revert "Add files via upload"
    This reverts commit 58dcf9b5dfb61d827b61158b1a3efca5b5b818b6.
    [TR-9 Run.cfg]
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2020-11-15 Updating PCB with links to corrected 3D models
    [Mainboard.kicad_pcb]
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2020-11-19 Adding mounting holes, U2. Corrected part number for J3.
    [HMI.sch]
2020-11-19 Better aligning key components to grid, closes #18
    Also:
    - Added 3D step model for display
    - Corrected DRC issues
    - Added 2mm chamfer on PCB edges
    - Reduced size for FPC slot, added rounded corners
    - Moved C12 to avoid being too close to display
    - Added dimension markers and PCB centerline
    [HMI.kicad_pcb]
2020-11-19 Fixing 3D models for push buttons
    [HMI.kicad_pcb]
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2020-11-19 Relocating J2 from underneath display
    This is a temporary fix. With issue #7, this part will change.
    [HMI.kicad_pcb]
2020-11-19 Oops, correcting display 3d model offset
    [HMI.kicad_pcb]
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
